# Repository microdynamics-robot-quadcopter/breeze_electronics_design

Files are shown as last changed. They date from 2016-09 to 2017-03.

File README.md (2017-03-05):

# breeze_electronics_design

## Description
This project is created and managed by EDA softwares, which contains the breeze quadcopter's component library, footprint library, schematic, printed circuit boards, etc.

## Note
Because of the changes in the project's requirements, we decided to use **Altium Designer** as the tool for developing the first edition of PCB rather than **KiCad**! So if you want to find the latest PCB design documents, please visit the **altium** directory.

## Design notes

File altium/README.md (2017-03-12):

# breeze_electronics_design





## Description
This project is created and managed by [Altium Designer](http://www.altium.com) softwares, which contains the breeze quadcopter's component library, footprint library, schematic, printed circuit boards, etc.

## Requirment
* Altium Designer 16.0.5(or higher version)

## Configuration
Open the Git Shell to download the **breeze_electronics_design** repository:
```bash
$> cd ~/Desktop
$> git clone https://github.com/microdynamics-quadcopter/breeze_electronics_design.git
```

Launch the **Altium Designer** software, and open **breeze_electronics_design.PrjPcb** file to view or develop PCB project.

## Schematic
* ### Motor
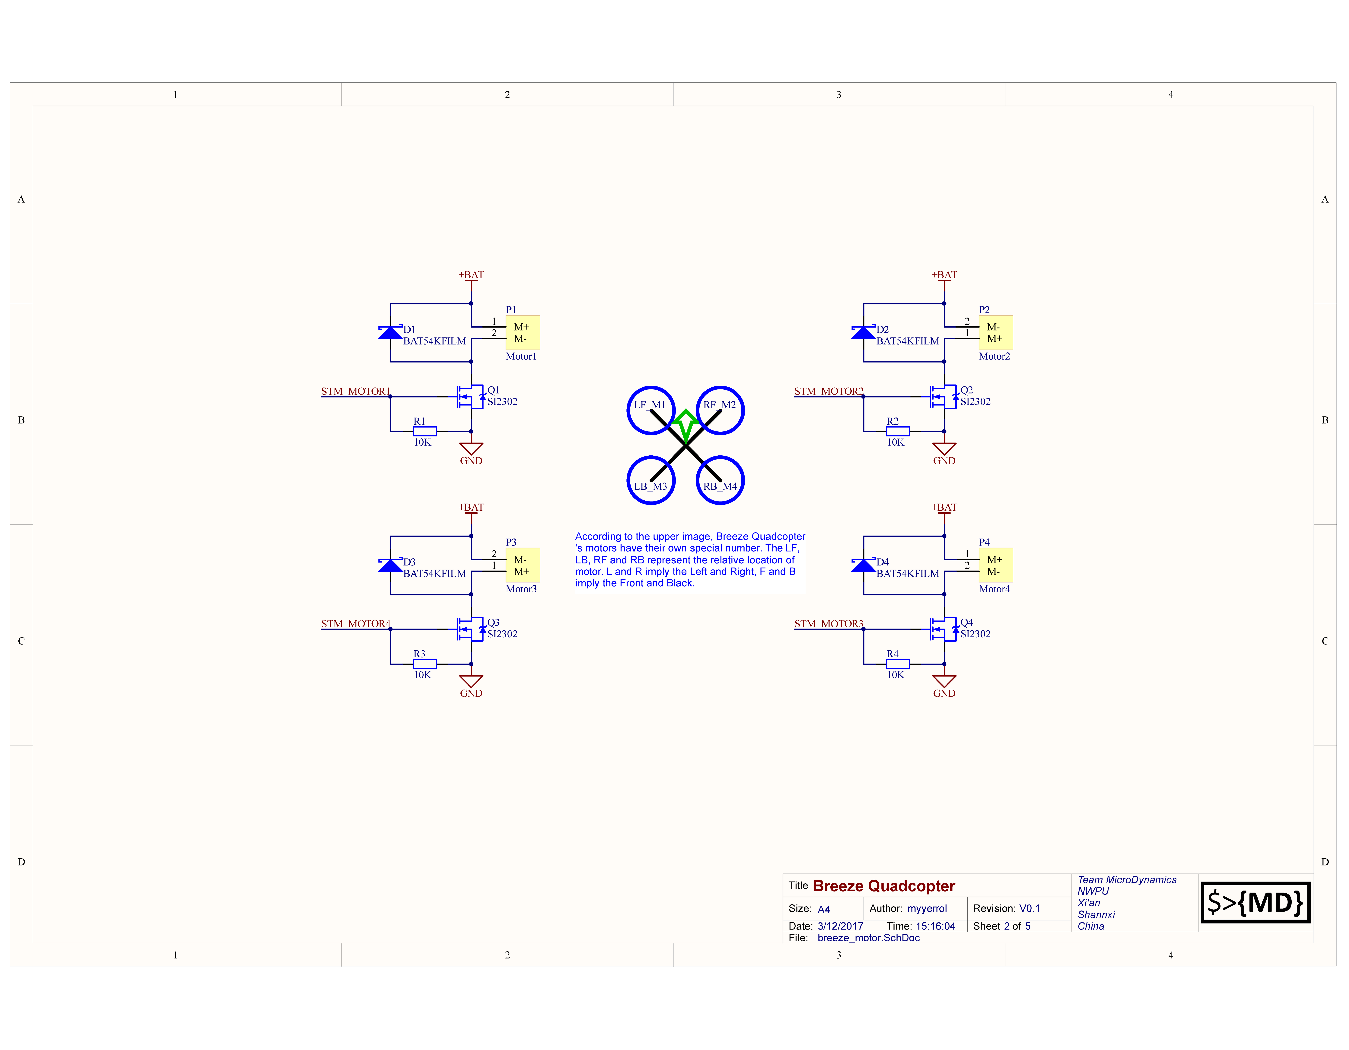
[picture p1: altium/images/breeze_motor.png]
breeze_motor


* ### Sensor
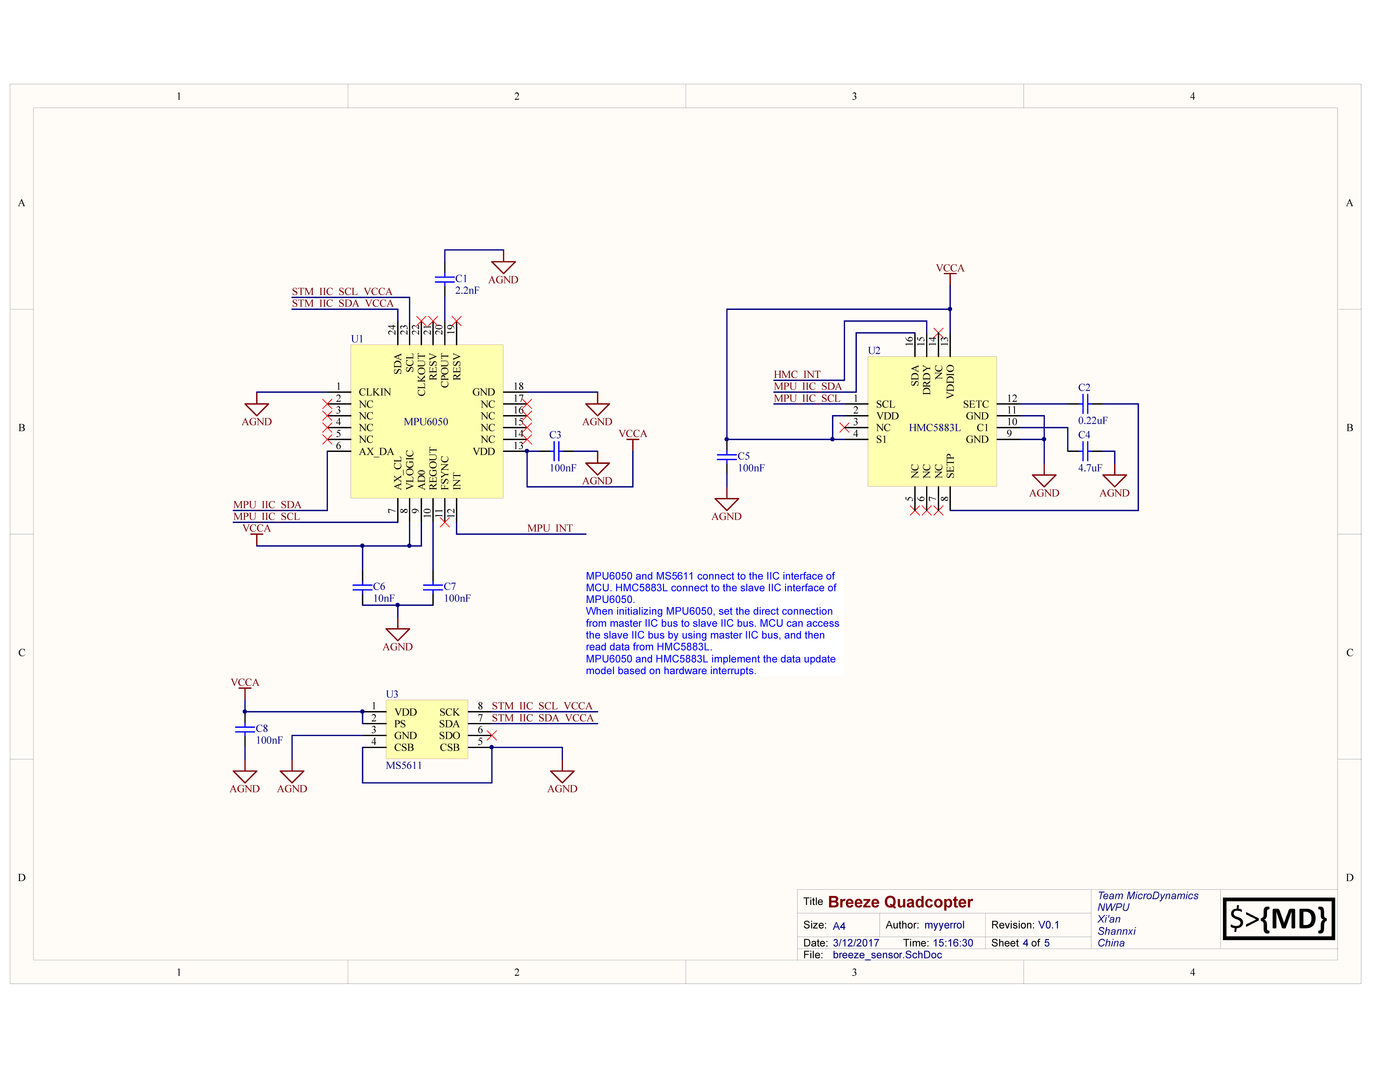
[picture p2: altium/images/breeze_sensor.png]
breeze_sensor


* ### Wireless
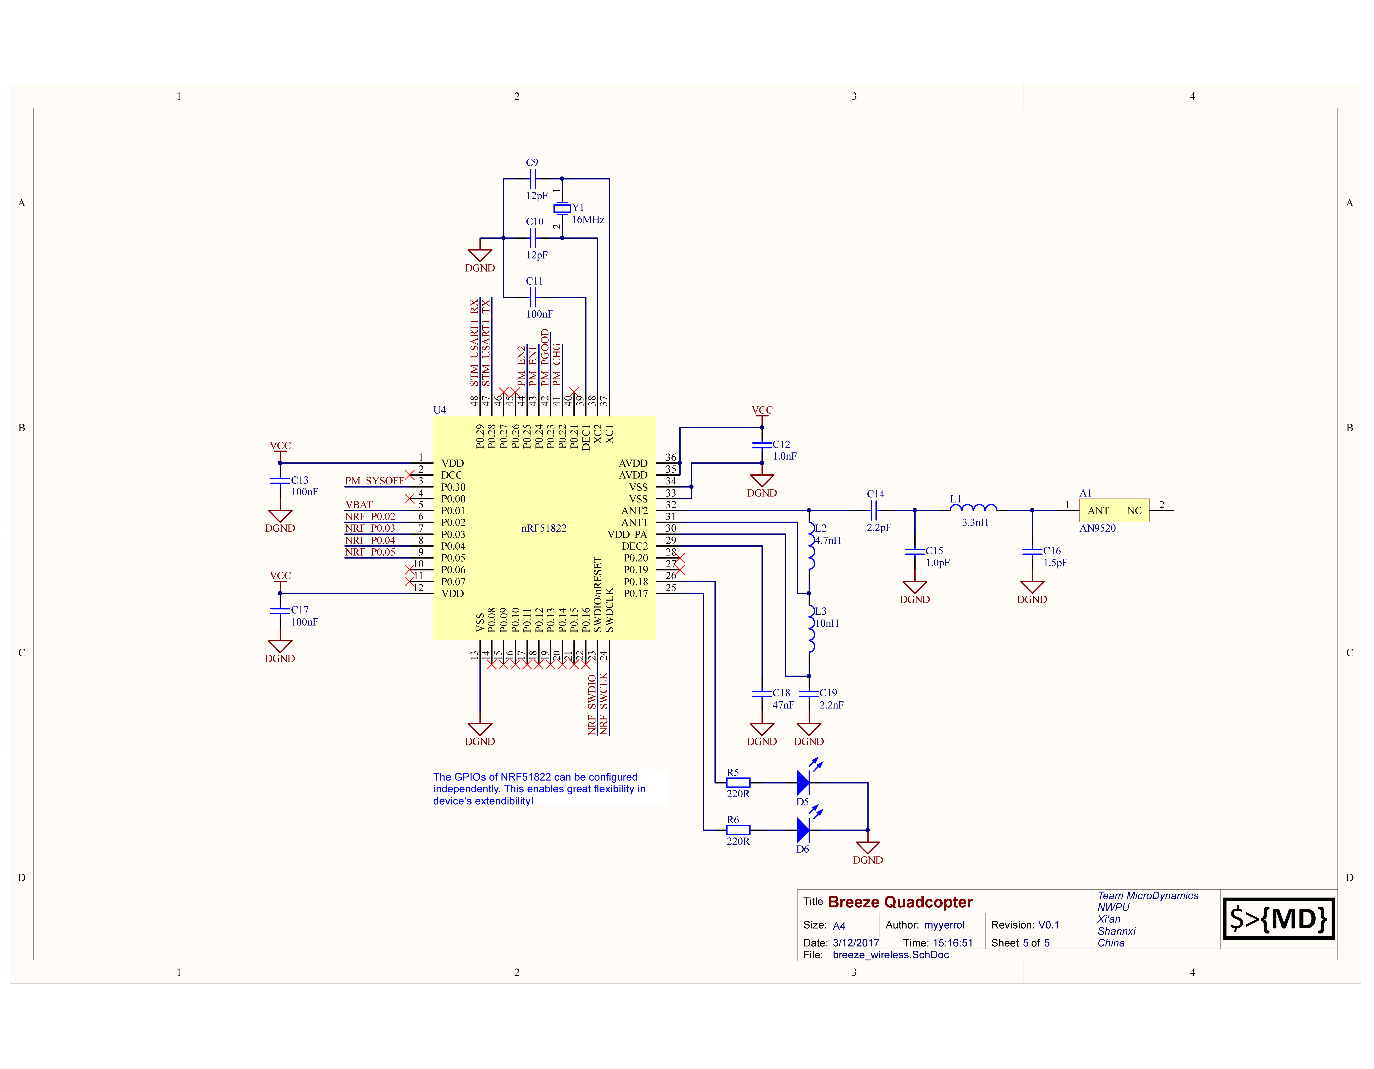
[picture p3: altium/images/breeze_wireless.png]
breeze_wireless


* ### Power
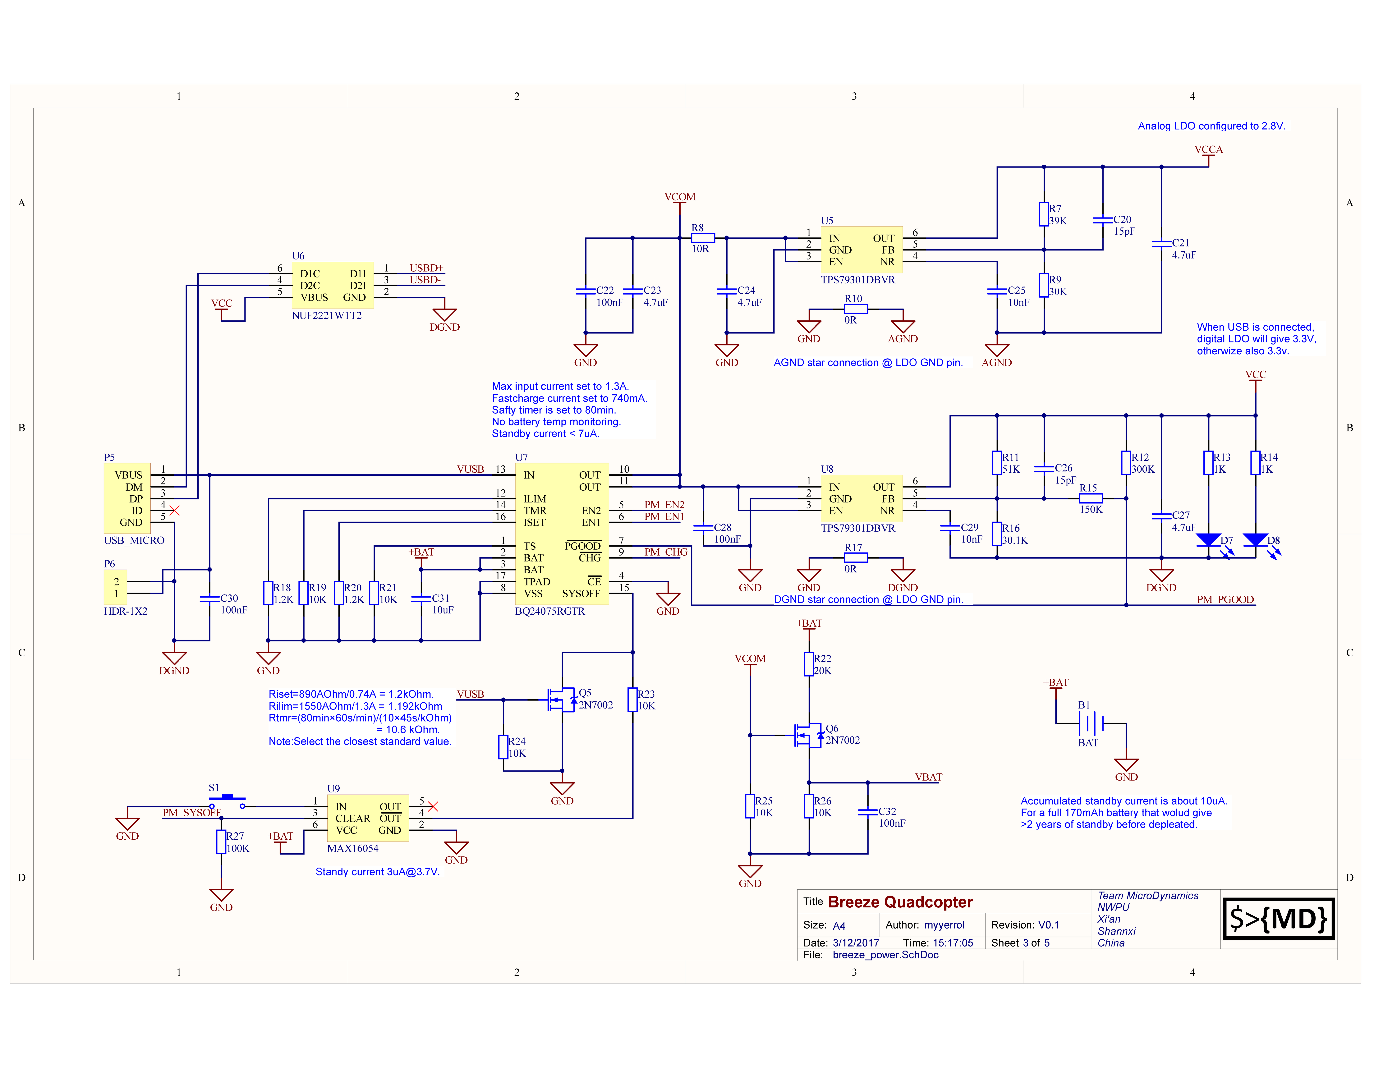
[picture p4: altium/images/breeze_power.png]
breeze_power


* ### Controller
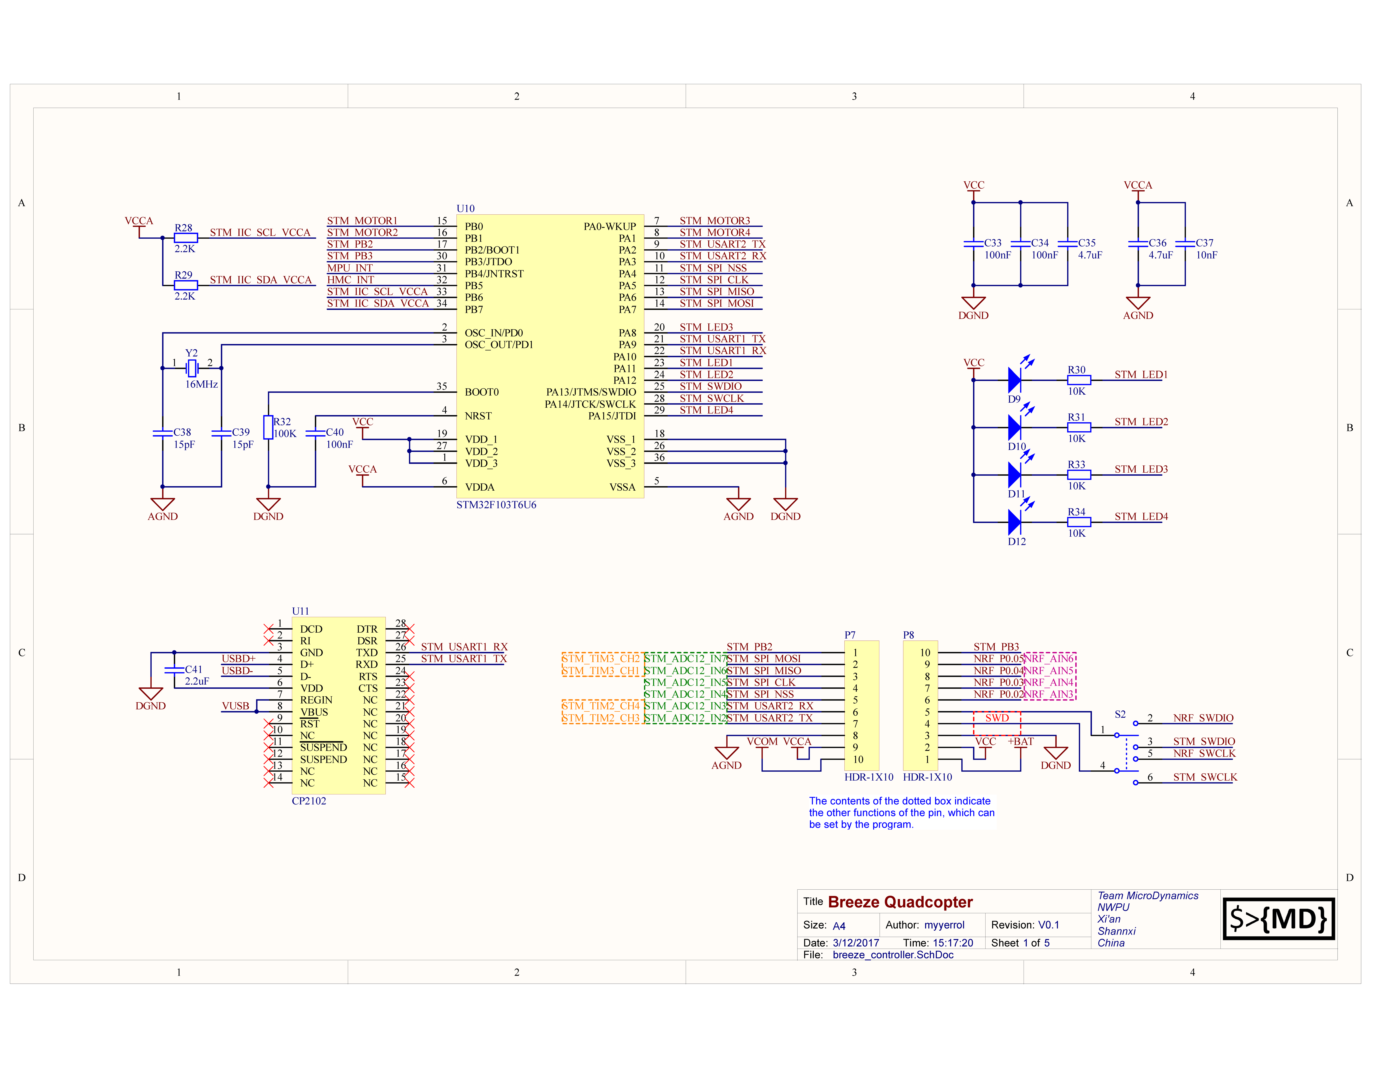
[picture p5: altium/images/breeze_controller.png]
breeze_controller


## PCB
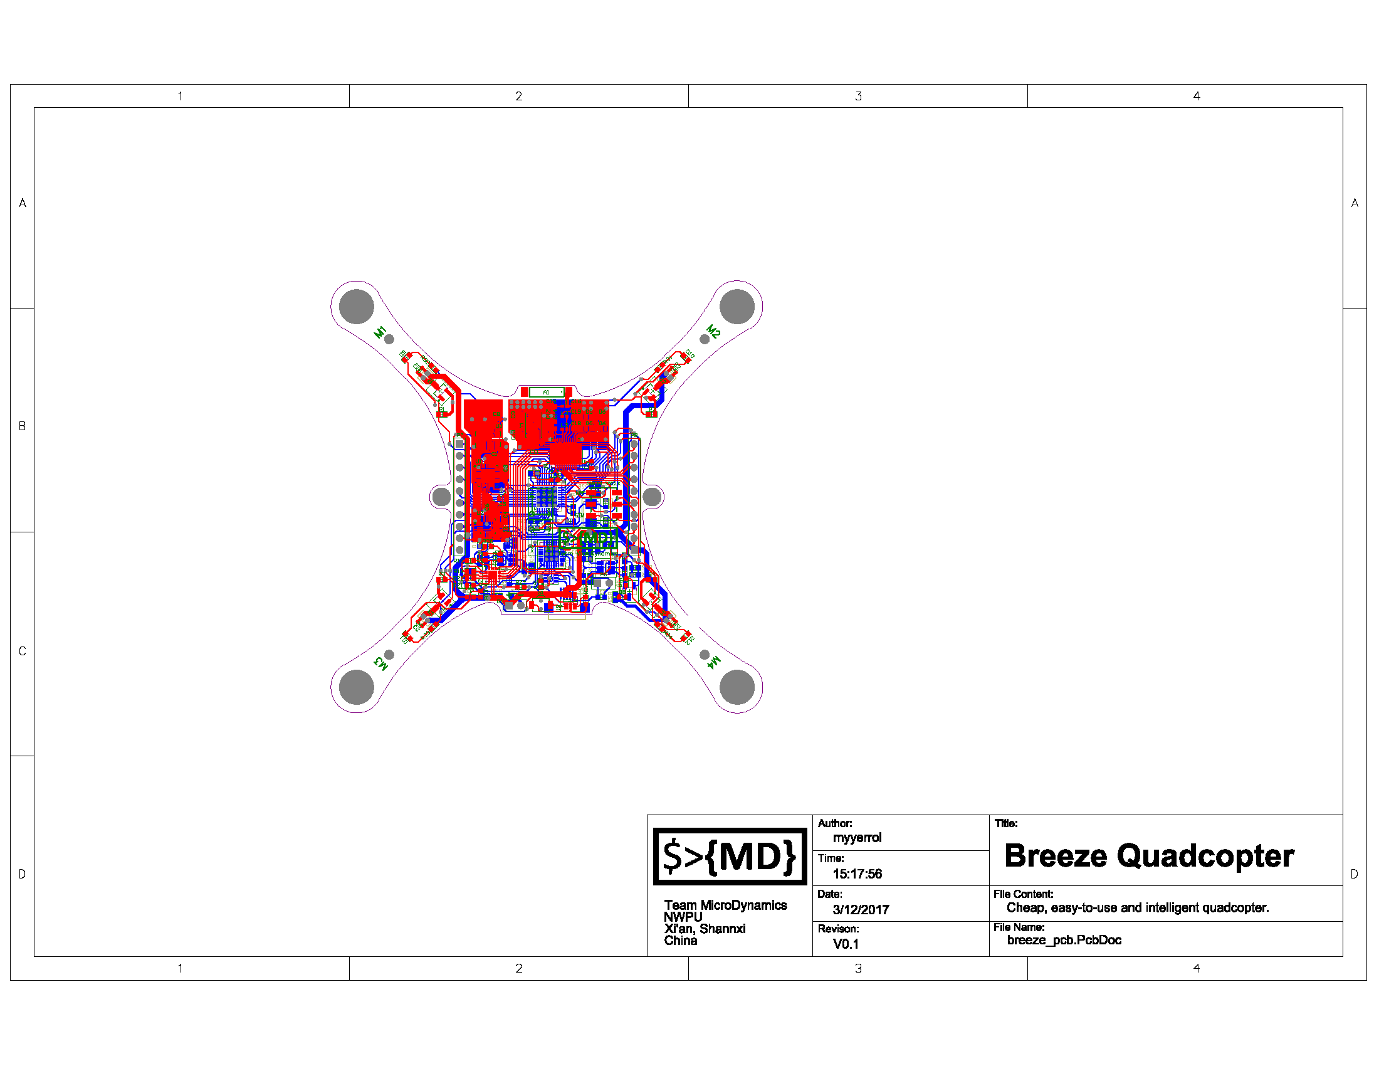
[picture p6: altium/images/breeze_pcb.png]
breeze_pcb


## Note
If you want to use our templates for schematic or pcb, please execute the **setup.bat** by double click.

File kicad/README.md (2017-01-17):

# breeze_electronics_design

## Description
This project is created and managed by [KiCad](http://kicad-pcb.org) software, which contains the breeze_std quadcopter's component library, footprint library, schematic, printed circuit boards, etc.

## PCB
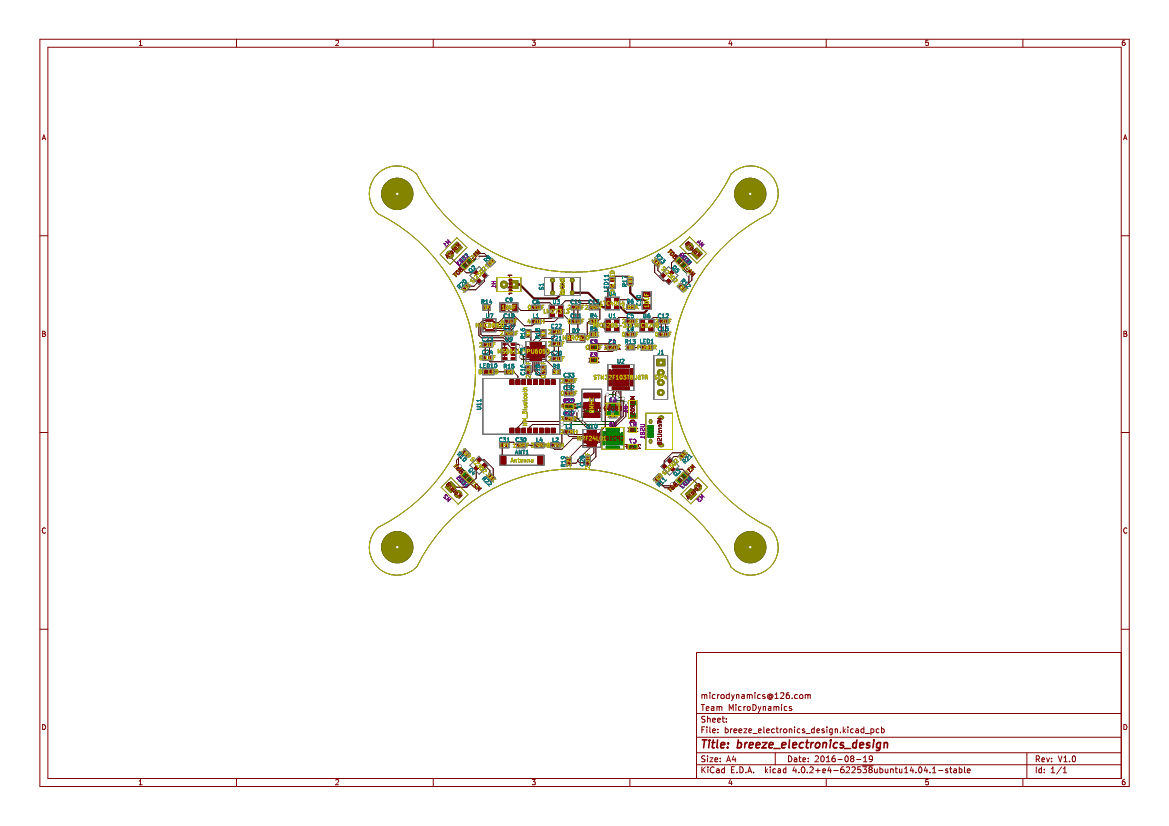
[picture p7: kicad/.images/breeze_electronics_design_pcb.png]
breeze_electronics_design_pcb


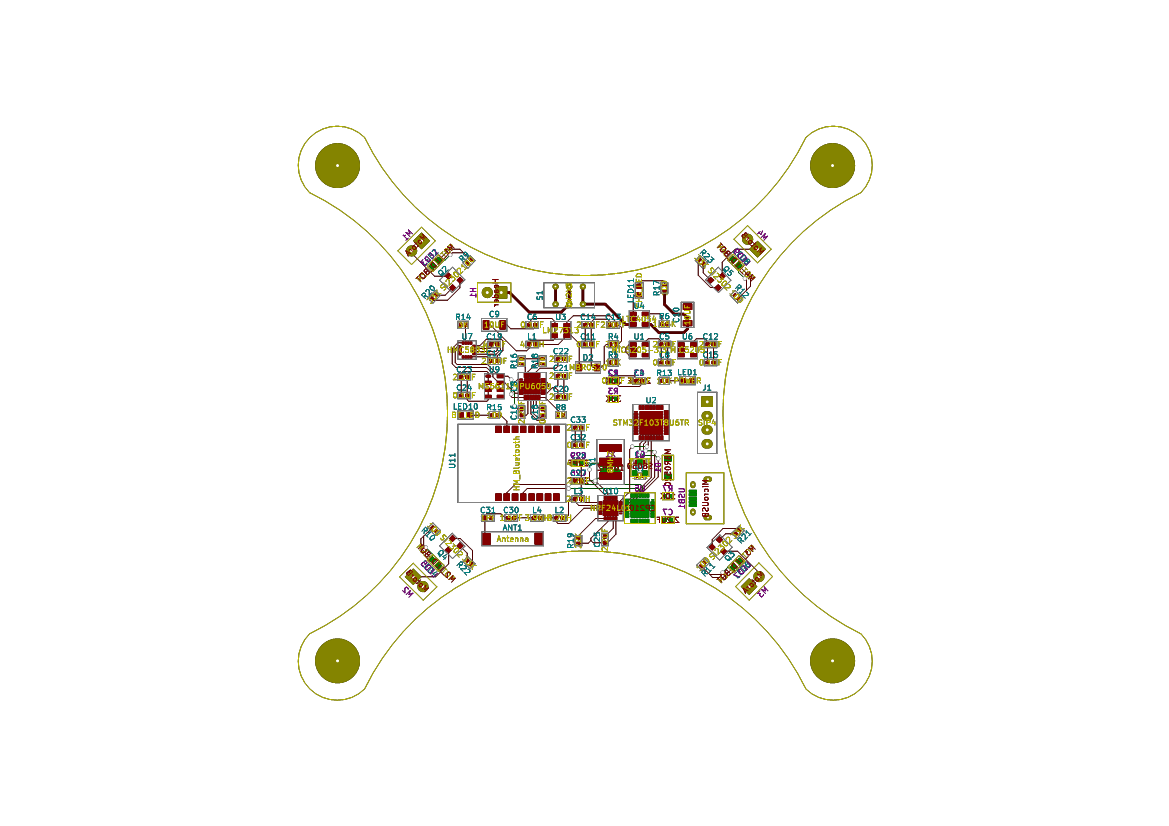
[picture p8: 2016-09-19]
kicad/.images/breeze_electronics_design_pcb_1.4.png

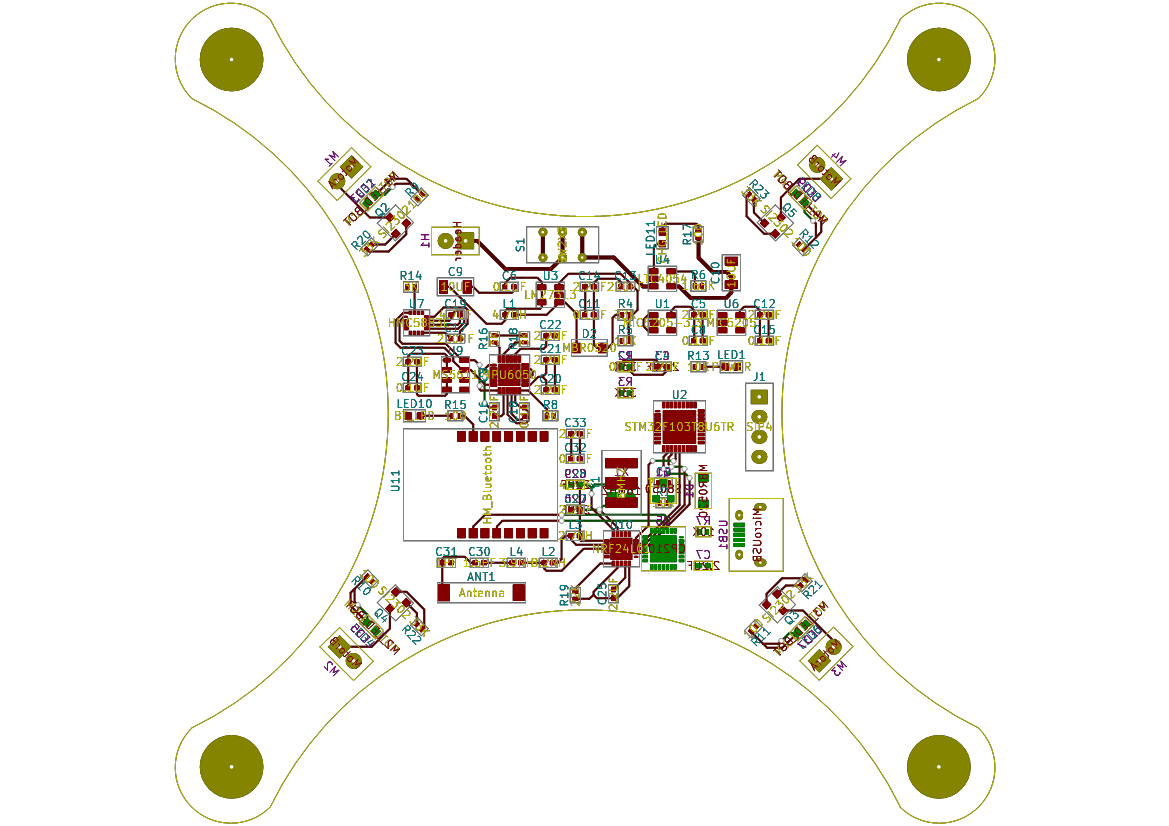
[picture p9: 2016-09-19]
kicad/.images/breeze_electronics_design_pcb_2.0.png

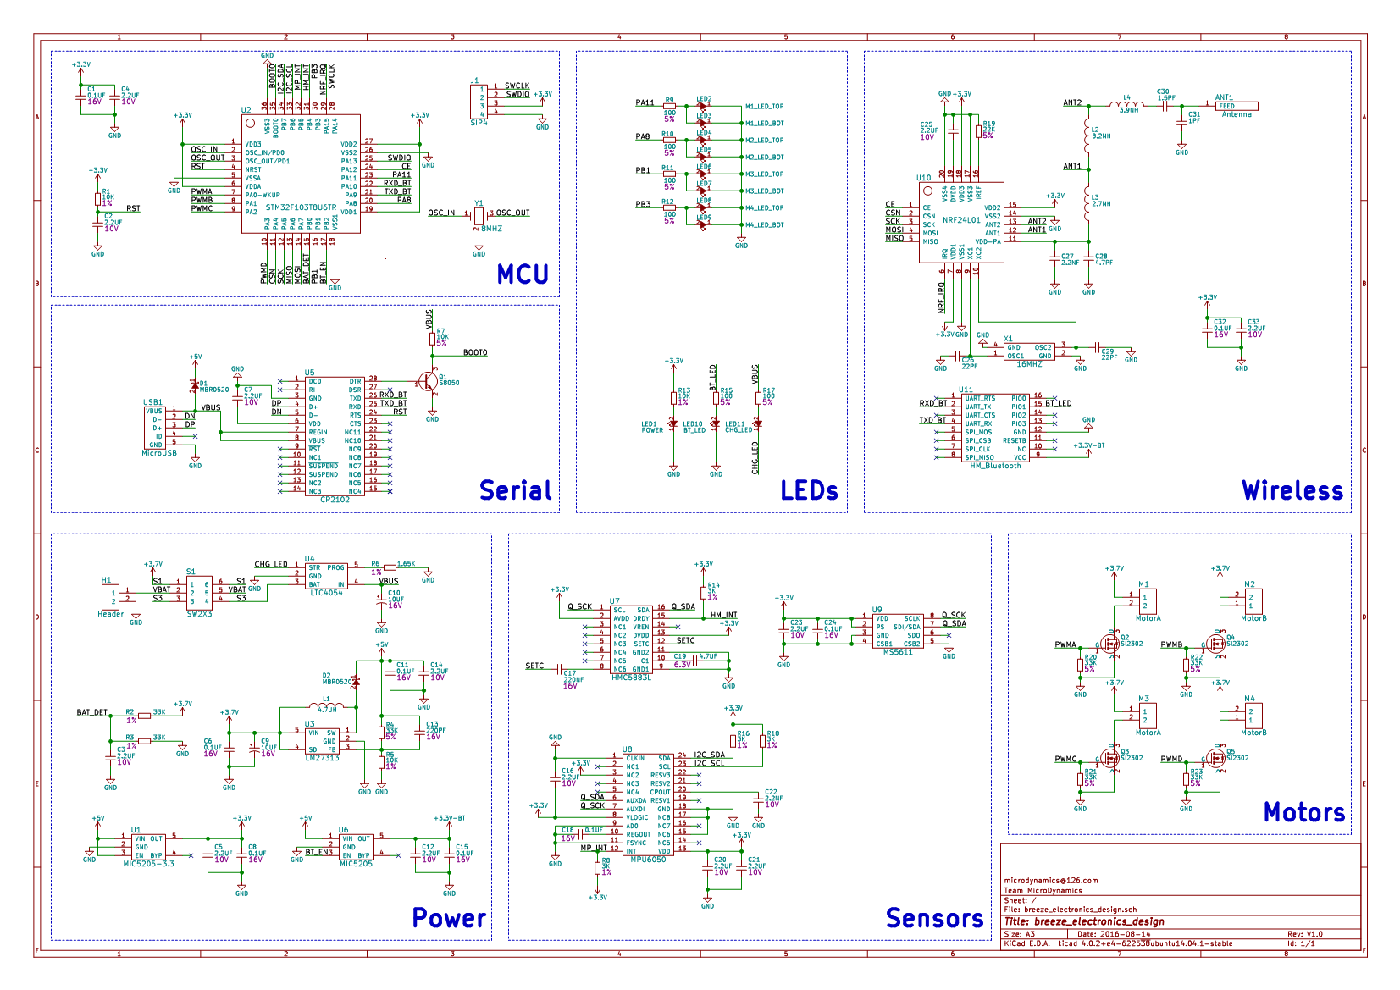
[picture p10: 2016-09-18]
kicad/.images/breeze_electronics_design_sch.png

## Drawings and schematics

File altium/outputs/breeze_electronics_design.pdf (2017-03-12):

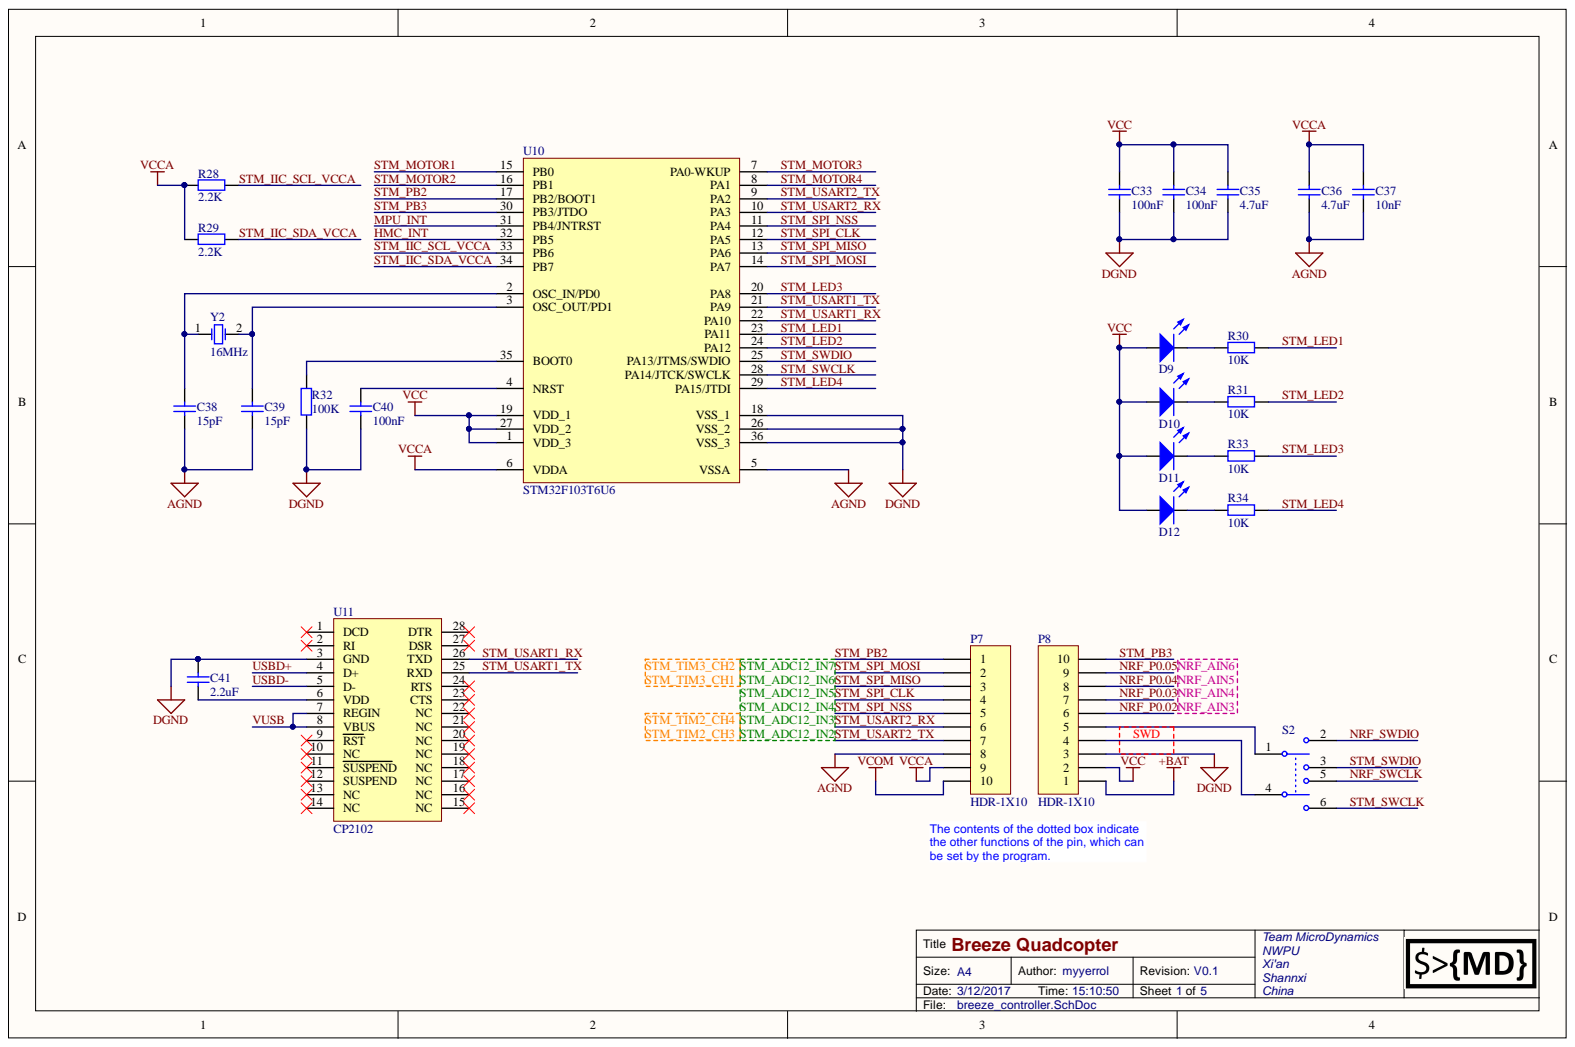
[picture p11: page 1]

The contents of the dotted box indicate
the other functions of the pin, which can
be set by the program.

Title Breeze Quadcopter | Team MicroDynamics NWPU Xi'an Shannxi China

Size: A4 | Author: myyerrol | Revision: V0.1
Date: 3/12/2017 Time: 15:10:50 | | Sheet 1 of 5
File: breeze_controller.SchDoc

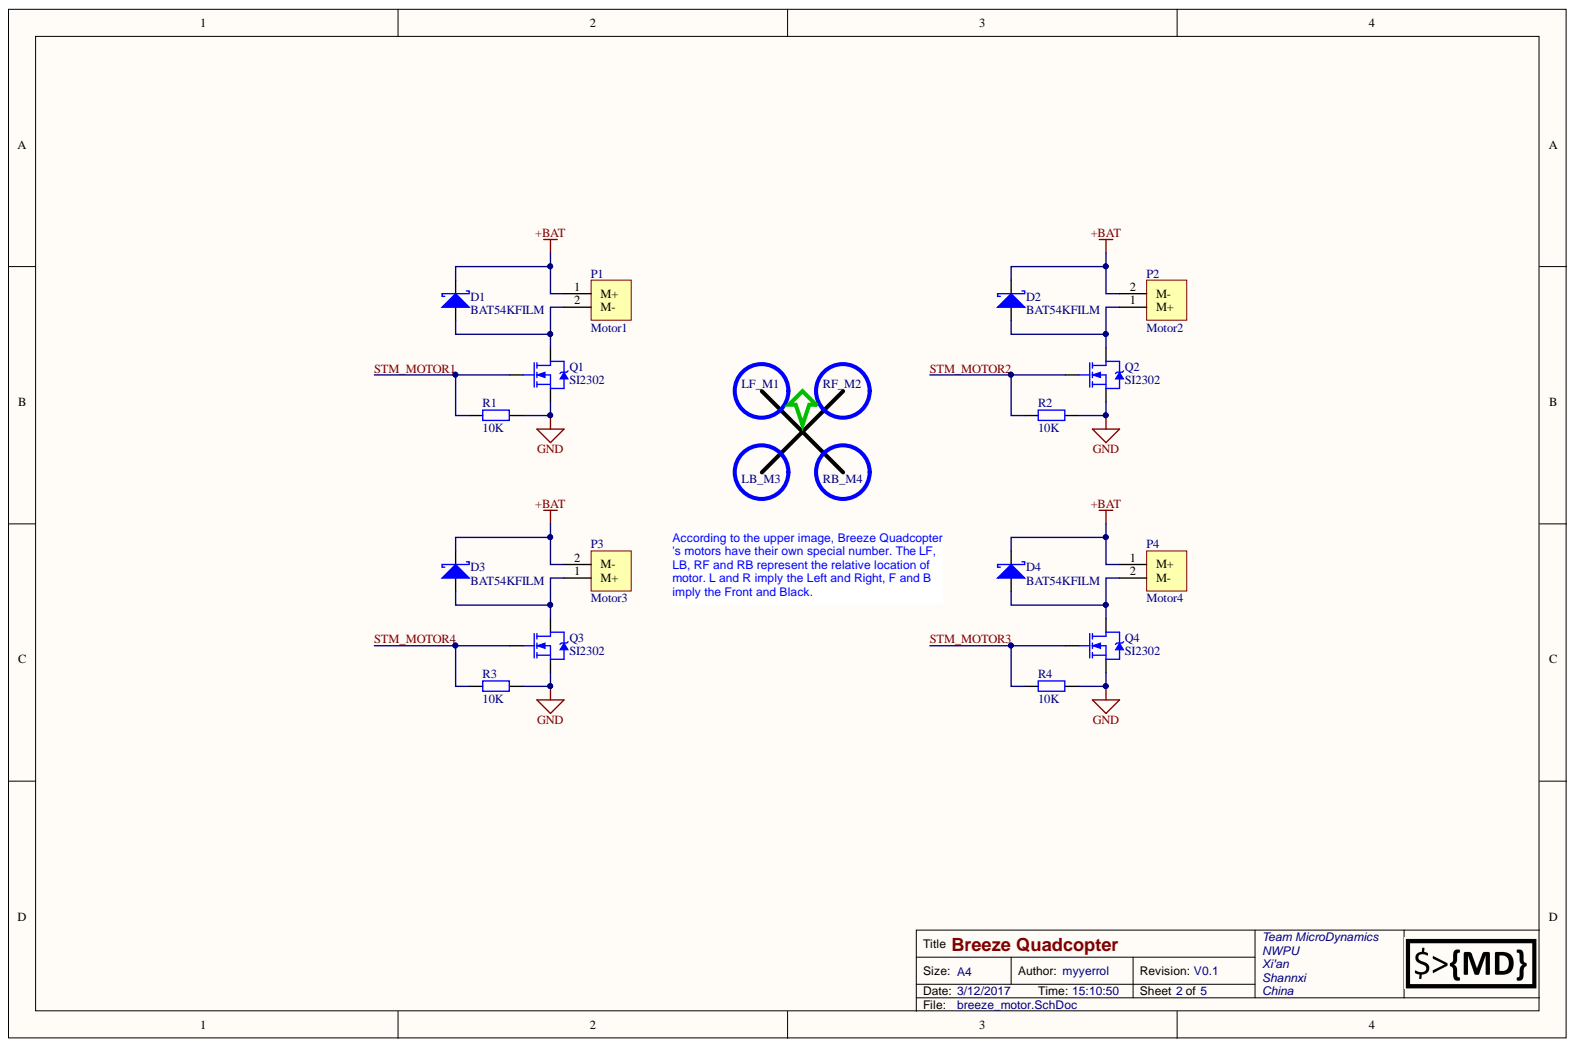
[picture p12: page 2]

According to the upper image, Breeze Quadcopter
's motors have their own special number. The LF,
LB, RF and RB represent the relative location of
motor. L and R imply the Left and Right, F and B
imply the Front and Black.

Title Breeze Quadcopter | Team MicroDynamics NWPU Xi'an Shannxi China

Size: A4 | Author: myyerrol | Revision: V0.1
Date: 3/12/2017 Time: 15:10:50 | | Sheet 2 of 5
File: breeze_motor.SchDoc

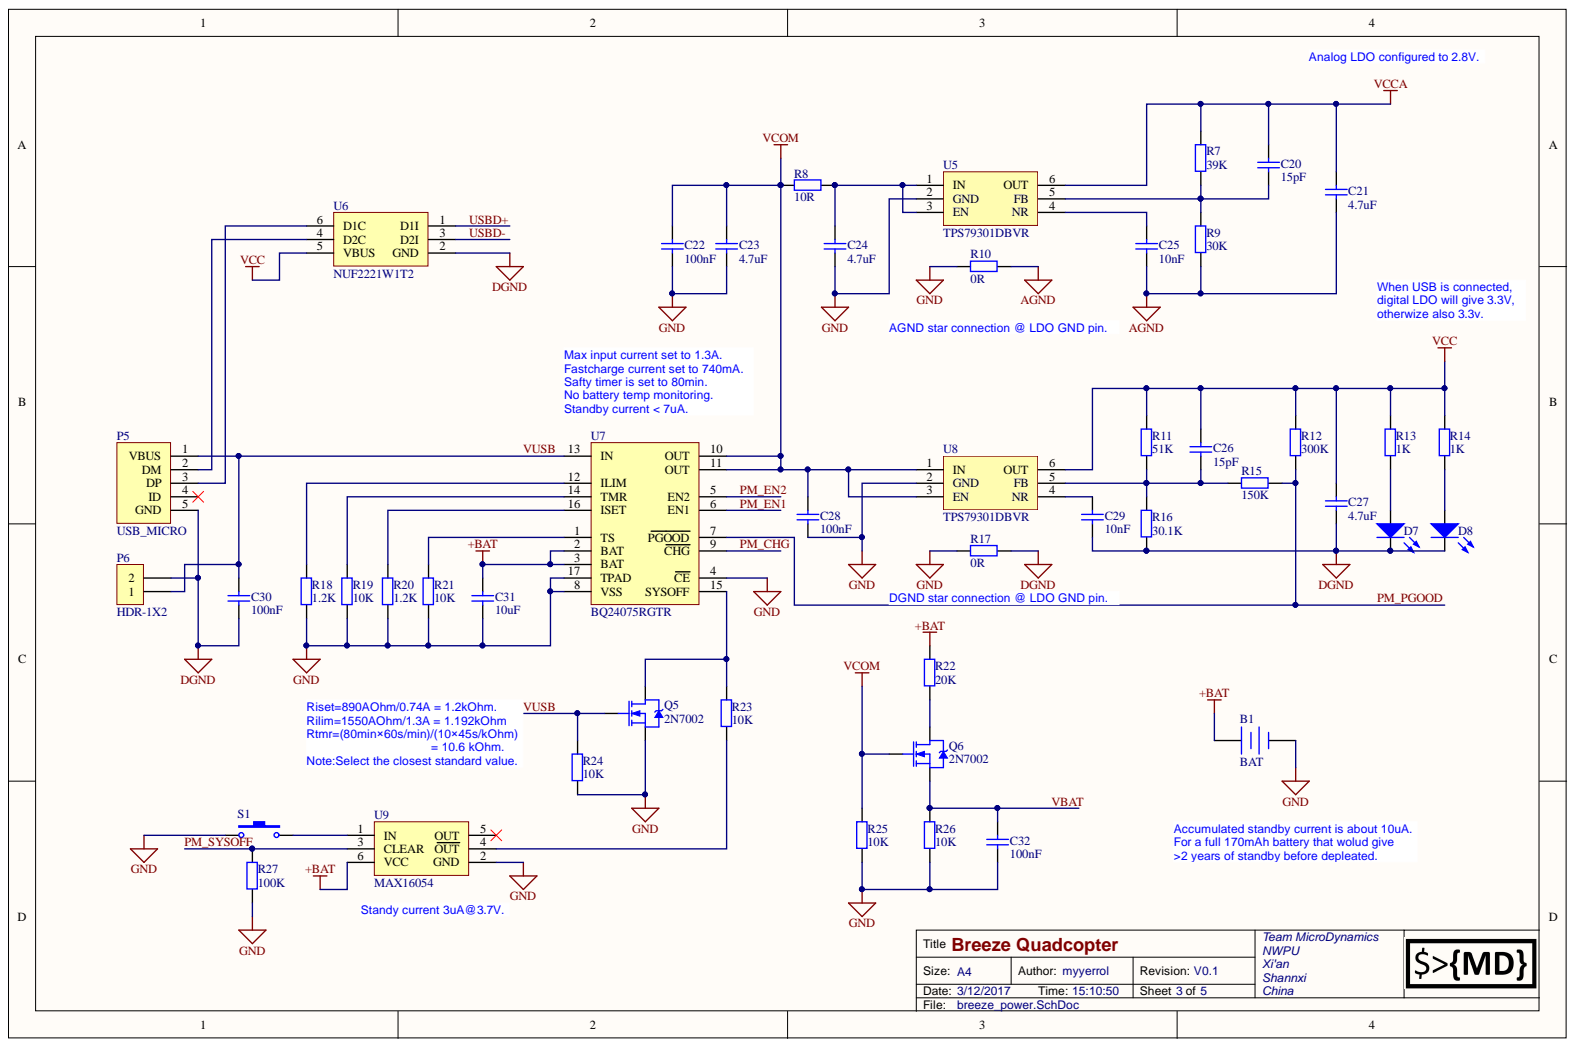
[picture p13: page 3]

Analog LDO configured to 2.8V.

When USB is connected,
digital LDO will give 3.3V,
otherwize also 3.3v.

AGND star connection @ LDO GND pin.

Max input current set to 1.3A.
Fastcharge current set to 740mA.
Safty timer is set to 80min.
No battery temp monitoring.
Standby current < 7uA.

DGND star connection @ LDO GND pin.

Note:Select the closest standard value.

Accumulated standby current is about 10uA.
For a full 170mAh battery that wolud give
>2 years of standby before depleated.

Title Breeze Quadcopter | Team MicroDynamics NWPU Xi'an Shannxi China

Size: A4 | Author: myyerrol | Revision: V0.1
Date: 3/12/2017 Time: 15:10:50 | | Sheet 3 of 5
File: breeze_power.SchDoc

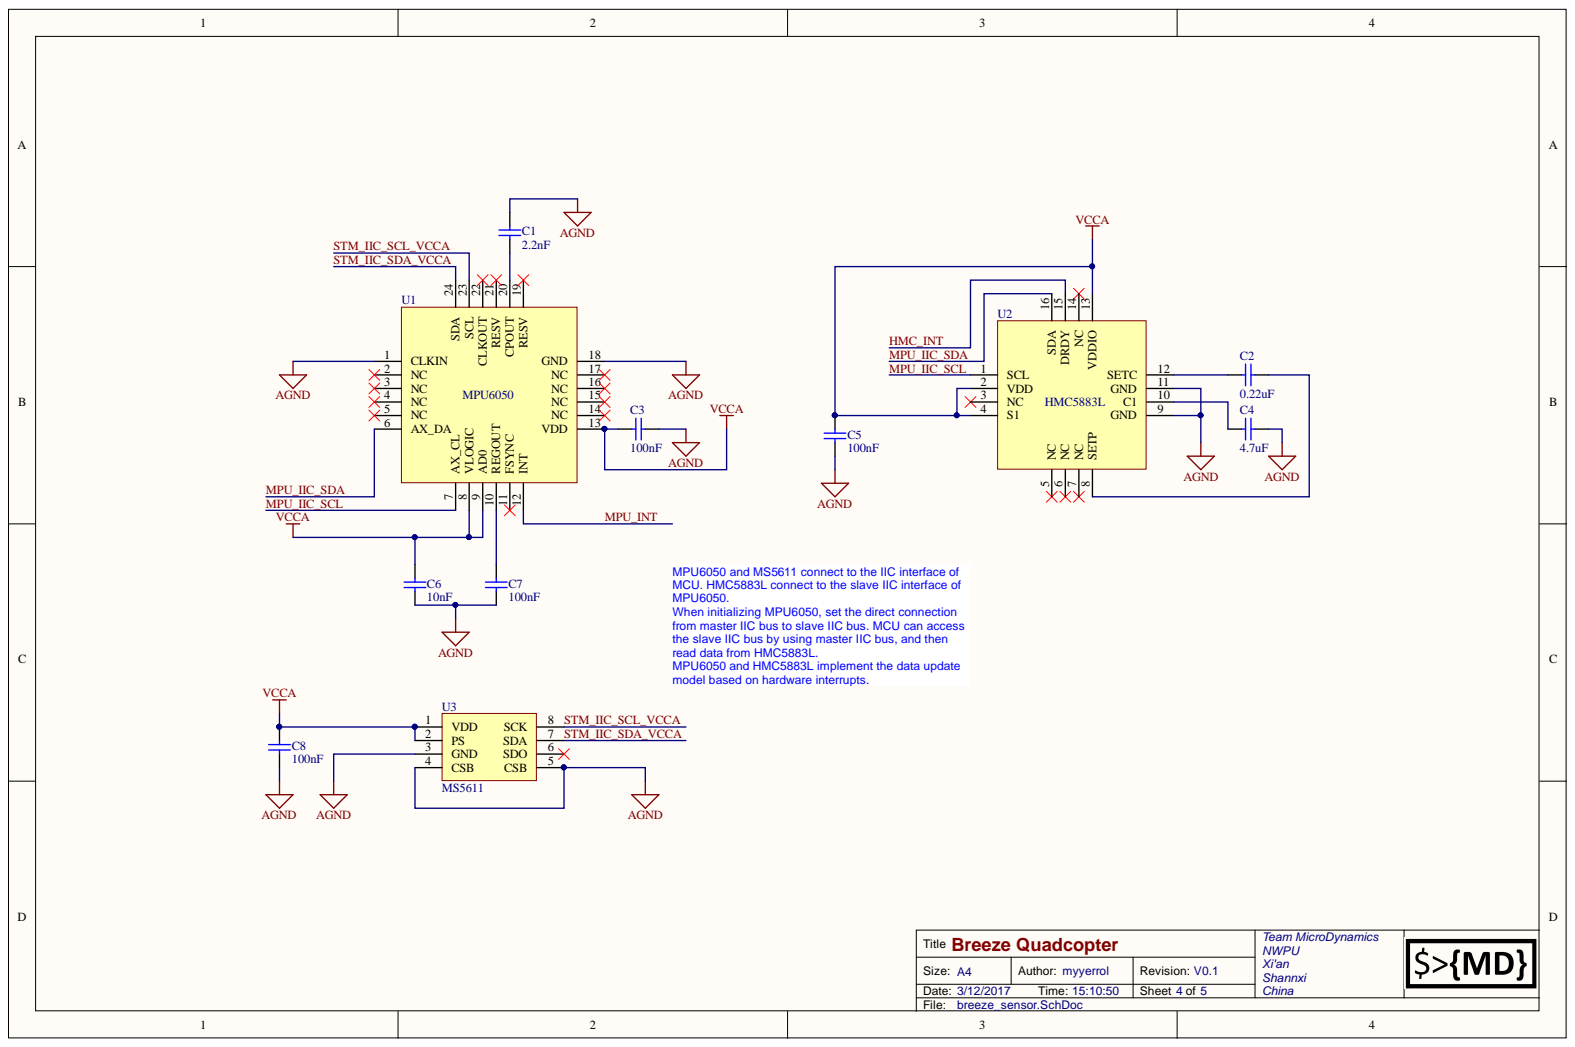
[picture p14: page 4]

12 DDIO 13 NC 14 DRDY 15 SDA 16

MPU6050 and MS5611 connect to the IIC interface of
MCU. HMC5883L connect to the slave IIC interface of
MPU6050.
When initializing MPU6050, set the direct connection
from master IIC bus to slave IIC bus. MCU can access
the slave IIC bus by using master IIC bus, and then
read data from HMC5883L.
MPU6050 and HMC5883L implement the data update
model based on hardware interrupts.

Title Breeze Quadcopter | Team MicroDynamics NWPU Xi'an Shannxi China

Size: A4 | Author: myyerrol | Revision: V0.1
Date: 3/12/2017 Time: 15:10:50 | | Sheet 4 of 5
File: breeze_sensor.SchDoc

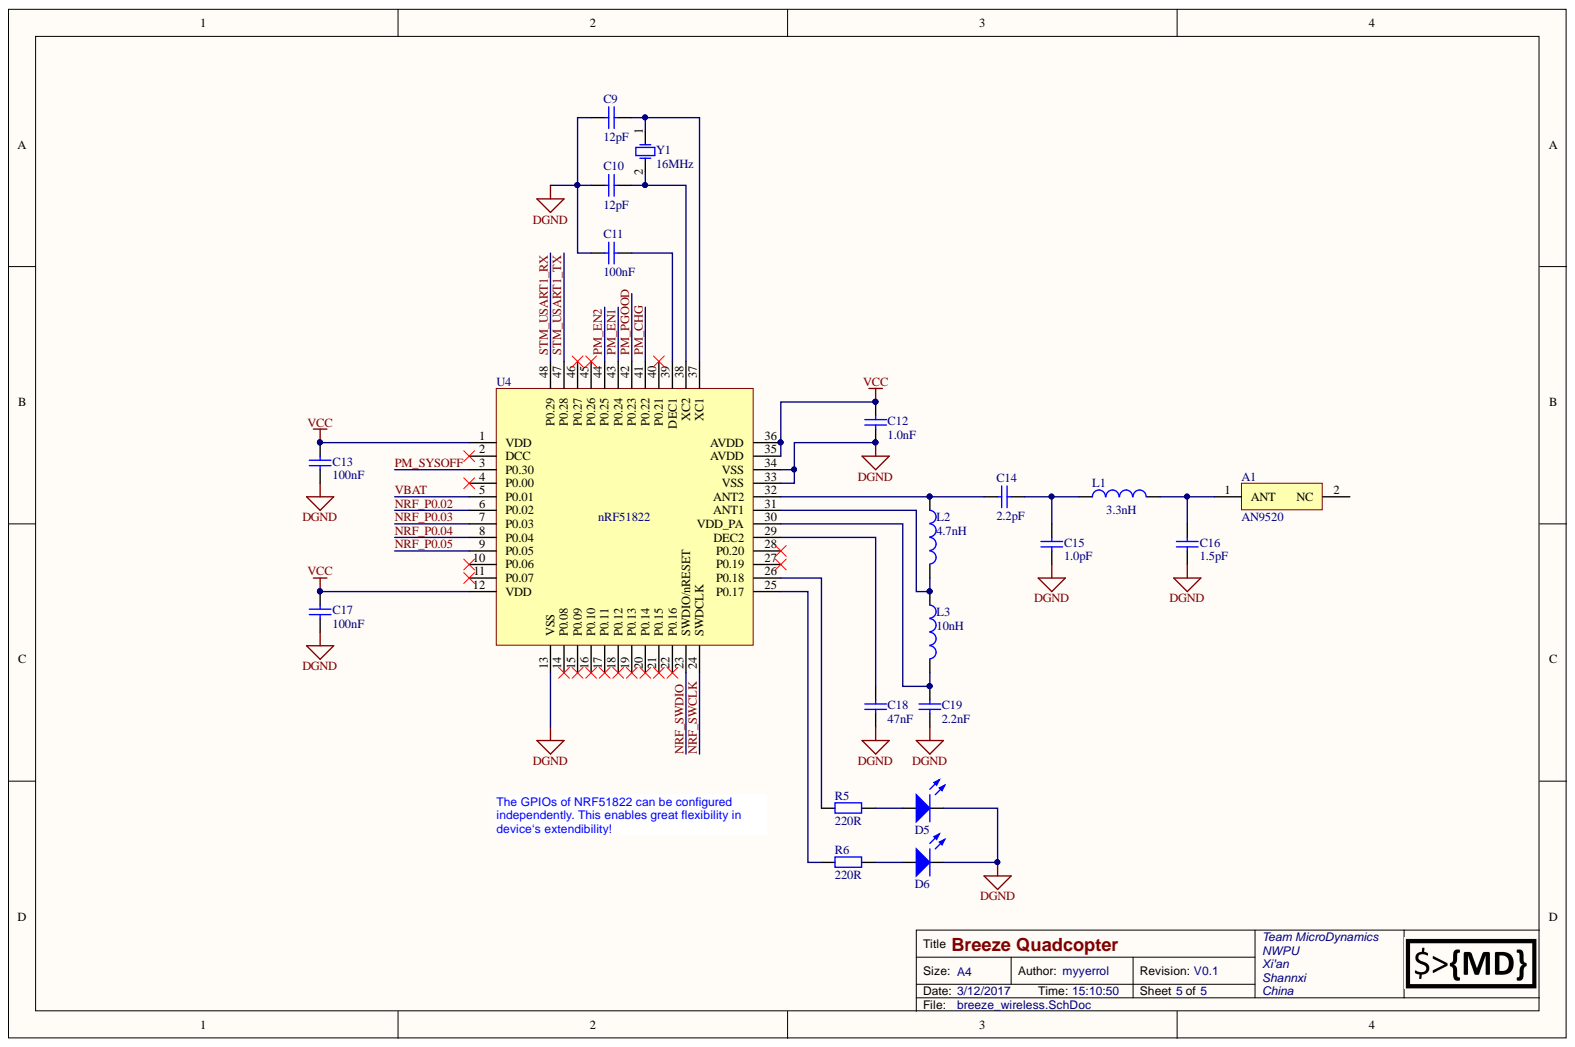
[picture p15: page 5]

The GPIOs of NRF51822 can be configured
independently. This enables great flexibility in
device‘s extendibility!

Title Breeze Quadcopter | Team MicroDynamics NWPU Xi'an Shannxi China

Size: A4 | Author: myyerrol | Revision: V0.1
Date: 3/12/2017 Time: 15:10:50 | | Sheet 5 of 5
File: breeze_wireless.SchDoc

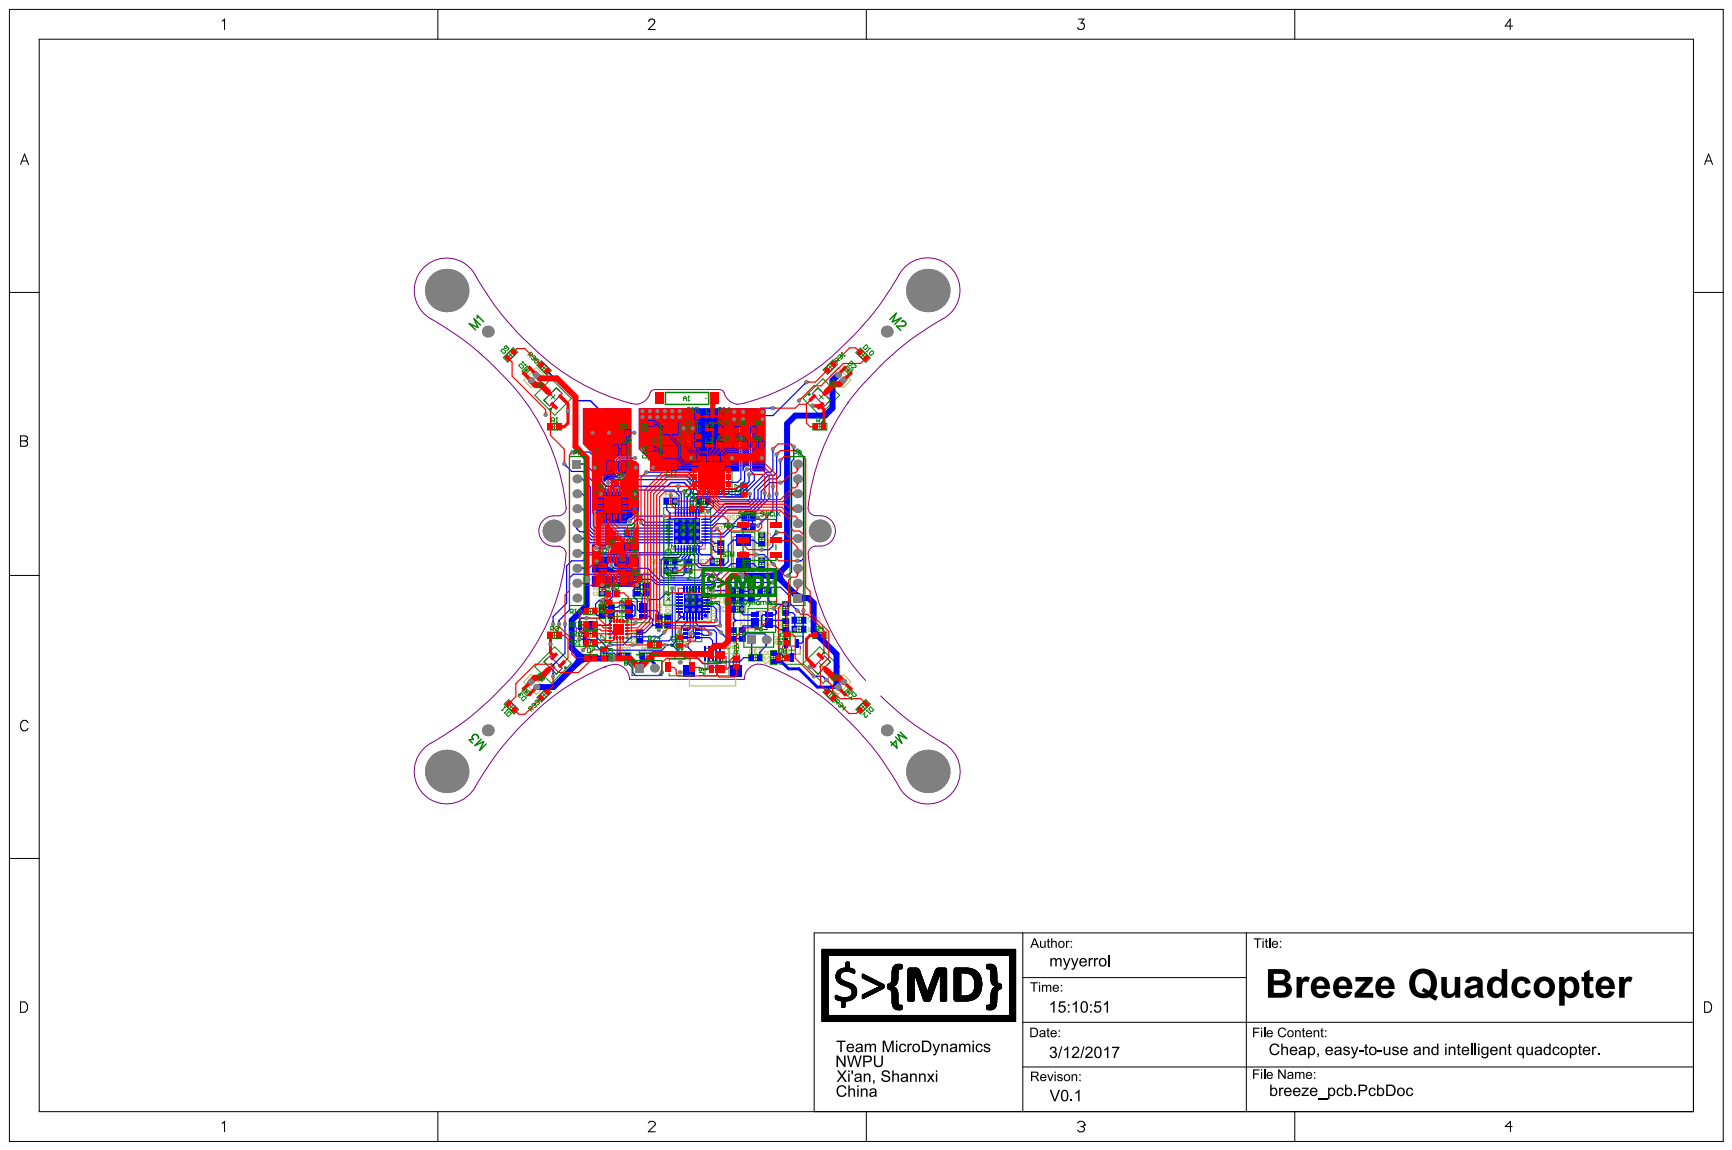
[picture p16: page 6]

| 3/12/2017 | 15:10:53
Print Date: | 12-Mar-17 | 3:10:58 PM
AN9520 | AN9520 | AN9520 | A1 | 2.4GHz Wireless Communication Antenna | 1
HDR-1X2 | BAT | BAT | B1 | Battery | 1
SMD-0603 | CAP-0603 | CAP-0603 | C1, C2, C3, C4, C5, C6, C7, C8, C9, C10,
| | | C11, C12, C13, C14, C15, C16, C17, C18,
| | | C19, C20, C21, C22, C23, C24, C25, C26,
| | | C27, C28, C29, C30, C31, C32, C33, C34,
| | | C35, C36, C37, C38, C39, C40, C41 | Capacitor | 41
SOD-523 | BAT54KFILM | BAT54KFILM | D1, D2, D3, D4 | Schottky Diode | 4
SMD-0603 | LED-0603 | LED-0603 | D5, D6, D7, D8, D9, D10, D11, D12 | LED | 8
SMD-0402 | IND-0402 | IND-0402 | L1, L2, L3 | Inductor | 3
HDRM-1X2 | Motor1 | Motor_A | P1 | Motor Header | 1
HDRM-1X2 | Motor2 | Motor_B | P2 | Motor Header | 1
HDRM-1X2 | Motor3 | Motor_B | P3 | Motor Header | 1
HDRM-1X2 | Motor4 | Motor_A | P4 | Motor Header | 1
USB_MICRO | USB_MICRO | USB_MICRO | P5 | Micro USB | 1
HDR-1X2 | HDR-1X2 | HDR-1X2 | P6 | Header 1X2 | 1
HDR-1X10 | HDR-1X10 | HDR-1X10 | P7, P8 | Header 1X10 | 2
SOT-23 | SI2302 | SI2302 | Q1, Q2, Q3, Q4 | N-Channel Enhancement Mode Field Effect
| | | | Transistor | 4
SOT-23 | 2N7002 | 2N7002 | Q5, Q6 | N-Channel Enhancement Mode Field Effect
| | | | Transistor | 2
SMD-0603 | RES-0603 | RES-0603 | R1, R2, R3, R4, R5, R6, R7, R8, R9, R10,
| | | R11, R12, R13, R14, R15, R16, R17, R18,
| | | R19, R20, R21, R22, R23, R24, R25, R26,
| | | R27, R28, R29, R30, R31, R32, R33, R34 | Resistor | 34
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

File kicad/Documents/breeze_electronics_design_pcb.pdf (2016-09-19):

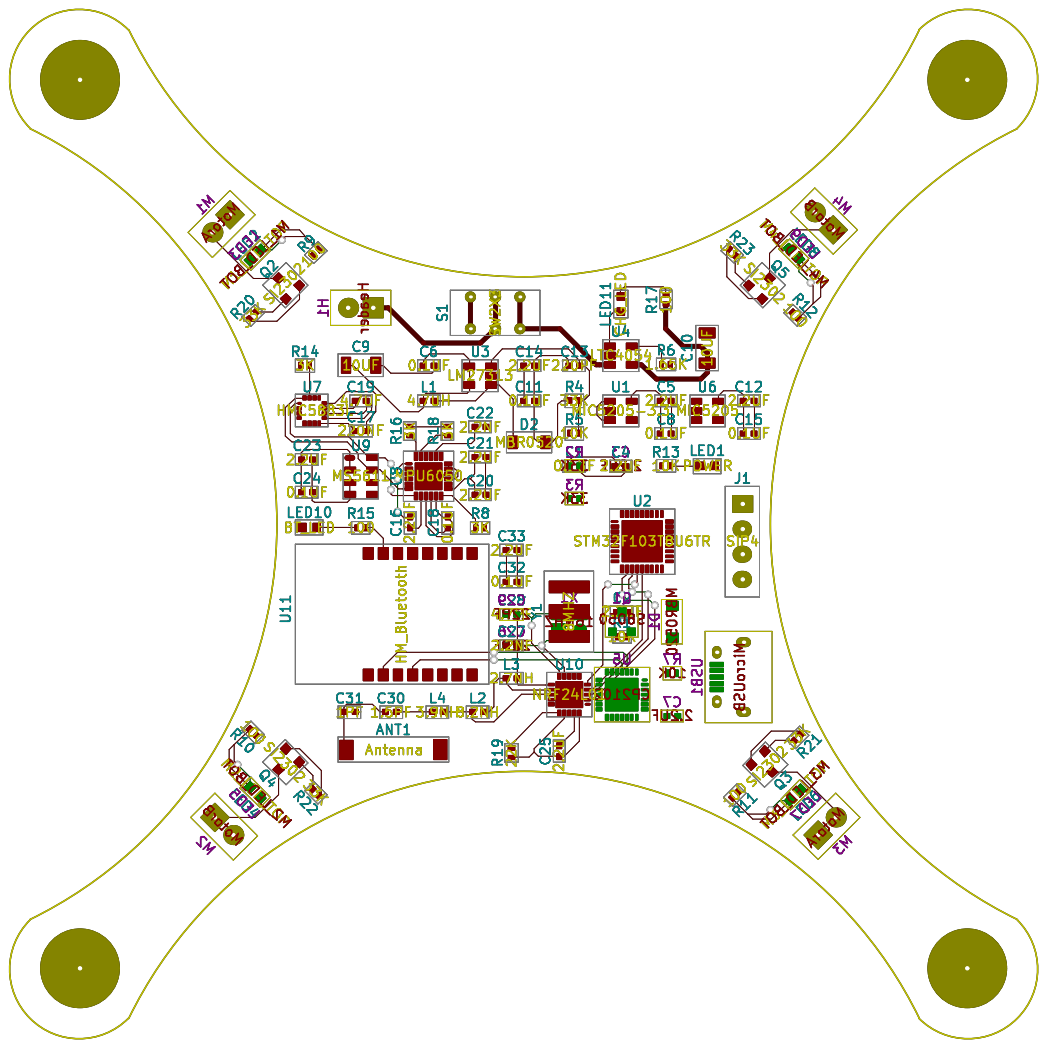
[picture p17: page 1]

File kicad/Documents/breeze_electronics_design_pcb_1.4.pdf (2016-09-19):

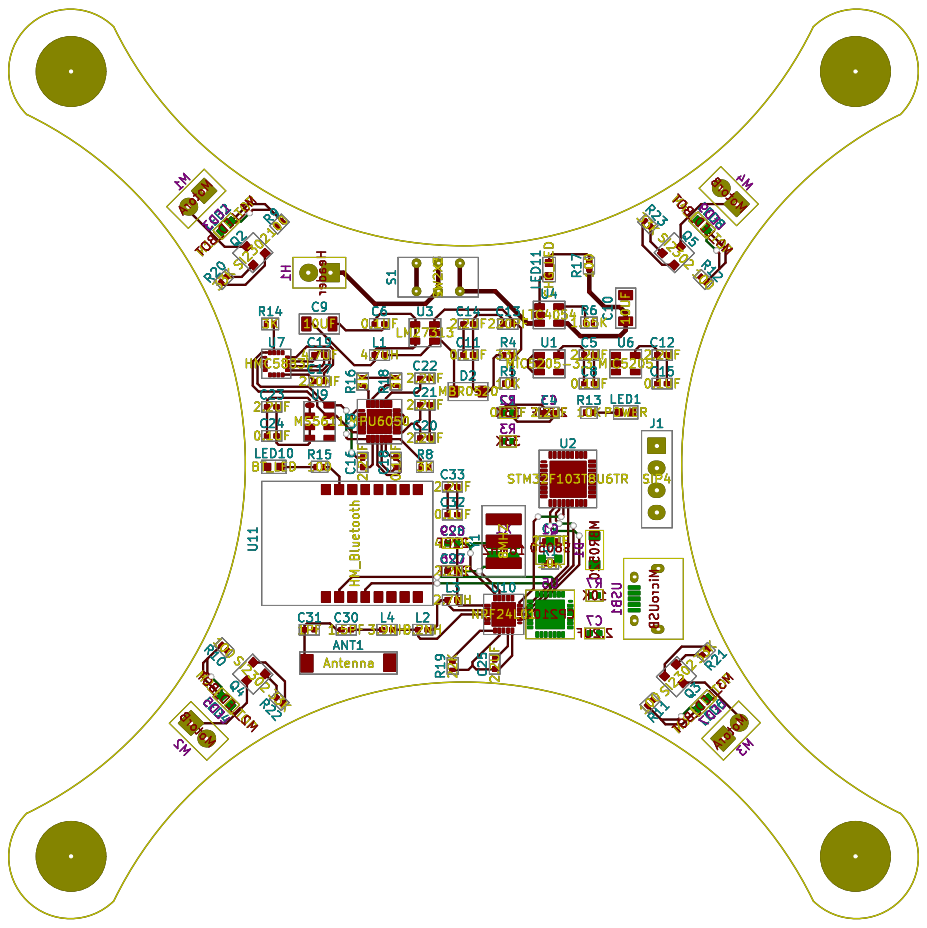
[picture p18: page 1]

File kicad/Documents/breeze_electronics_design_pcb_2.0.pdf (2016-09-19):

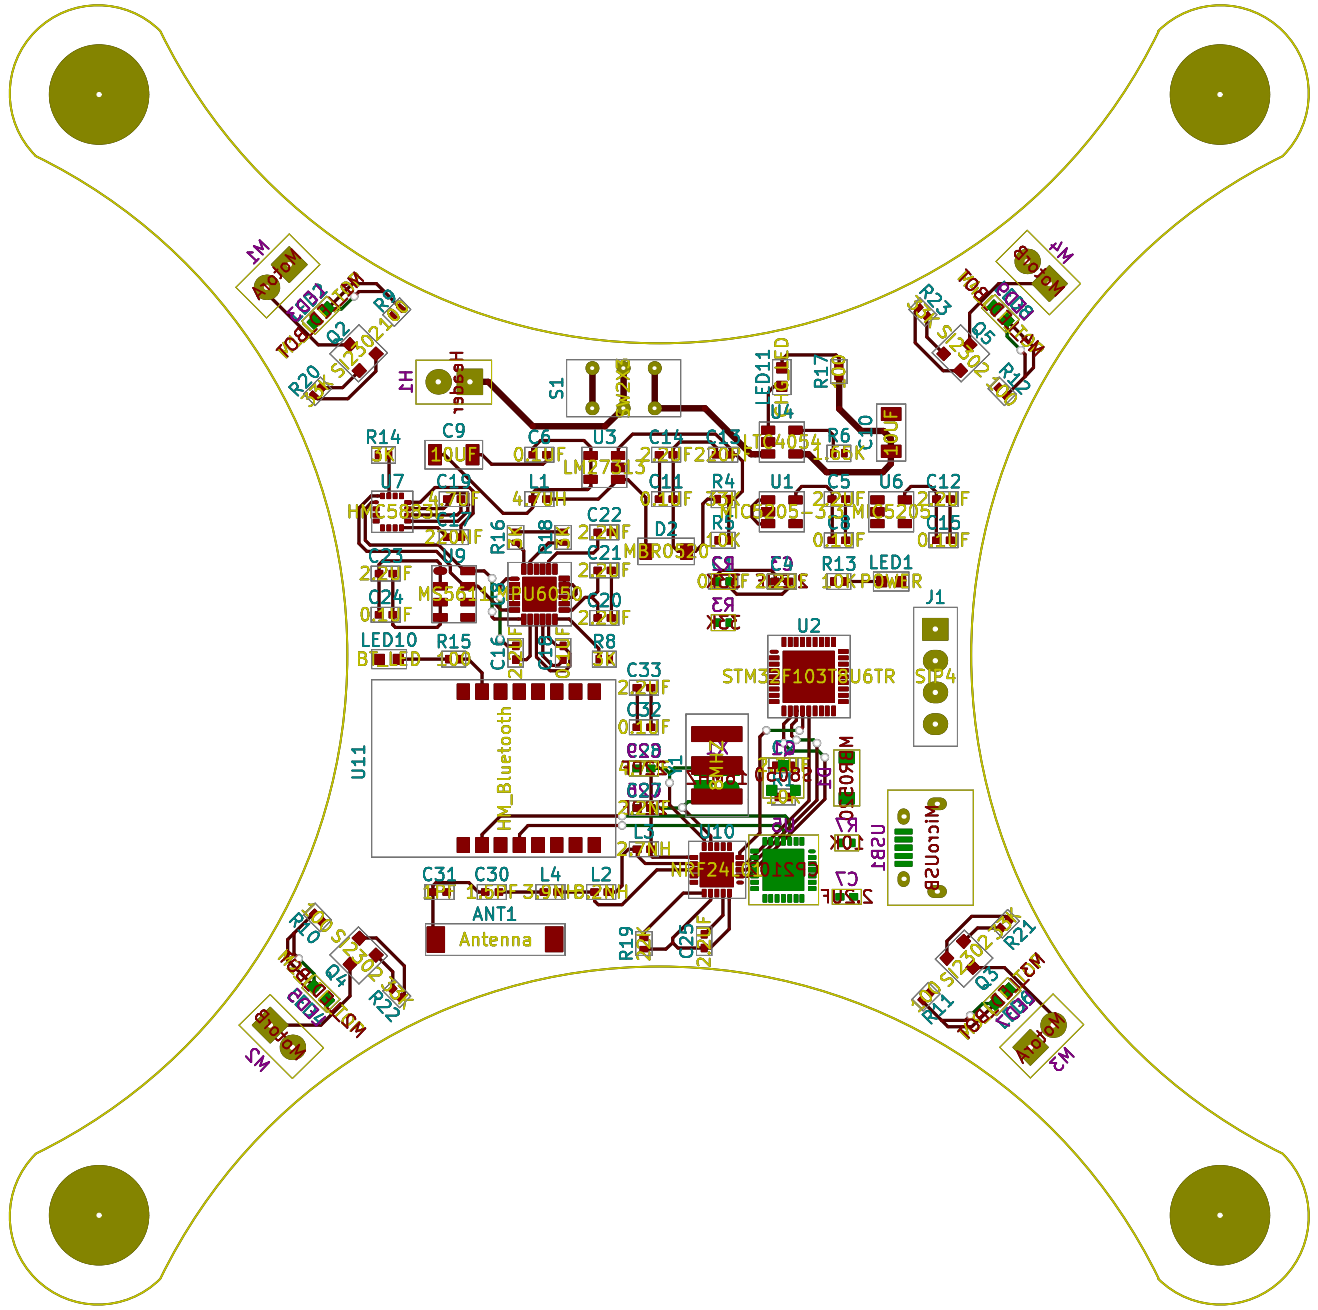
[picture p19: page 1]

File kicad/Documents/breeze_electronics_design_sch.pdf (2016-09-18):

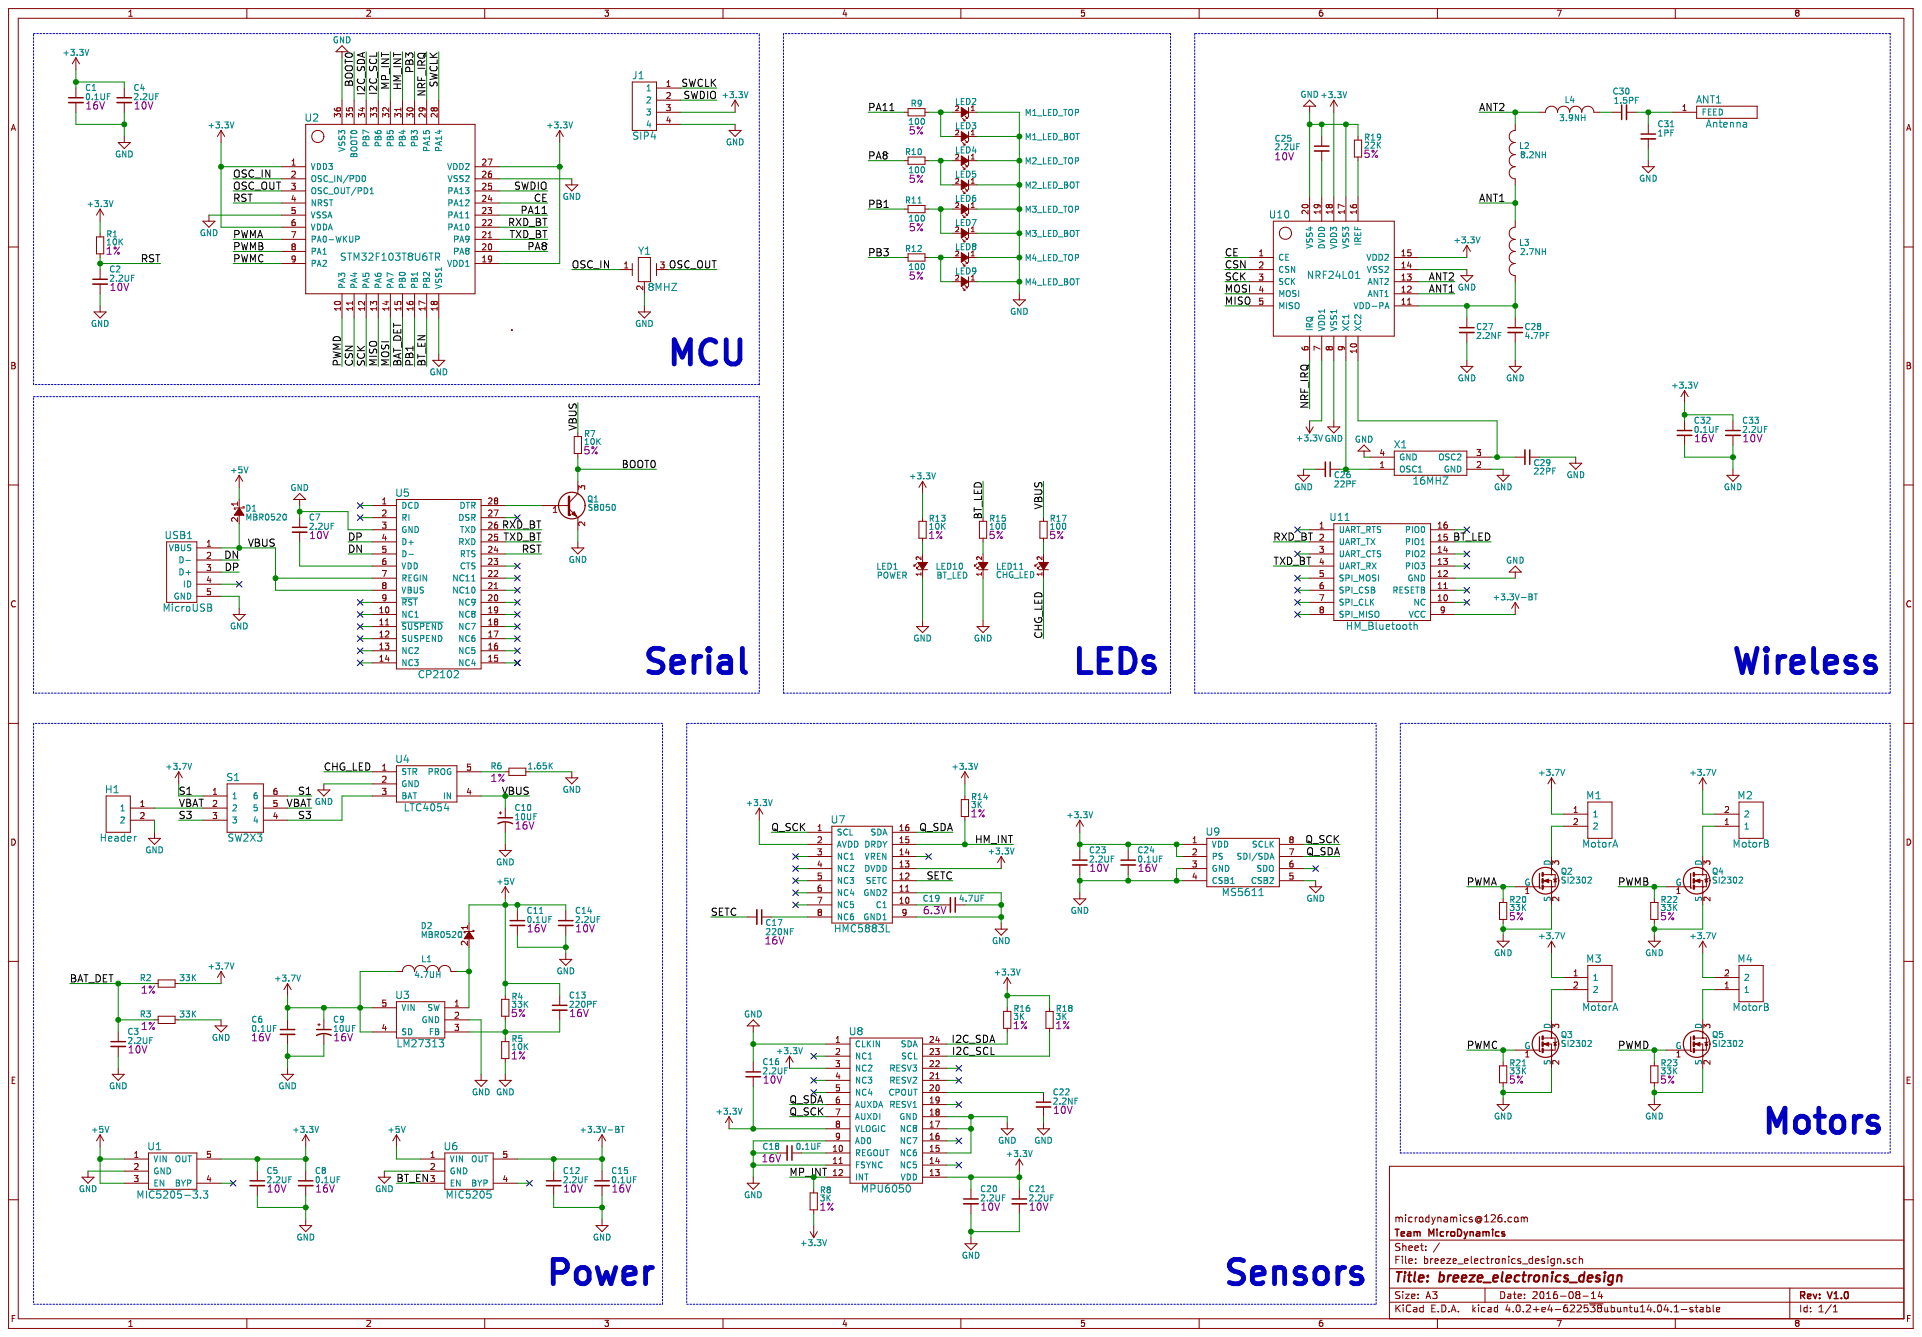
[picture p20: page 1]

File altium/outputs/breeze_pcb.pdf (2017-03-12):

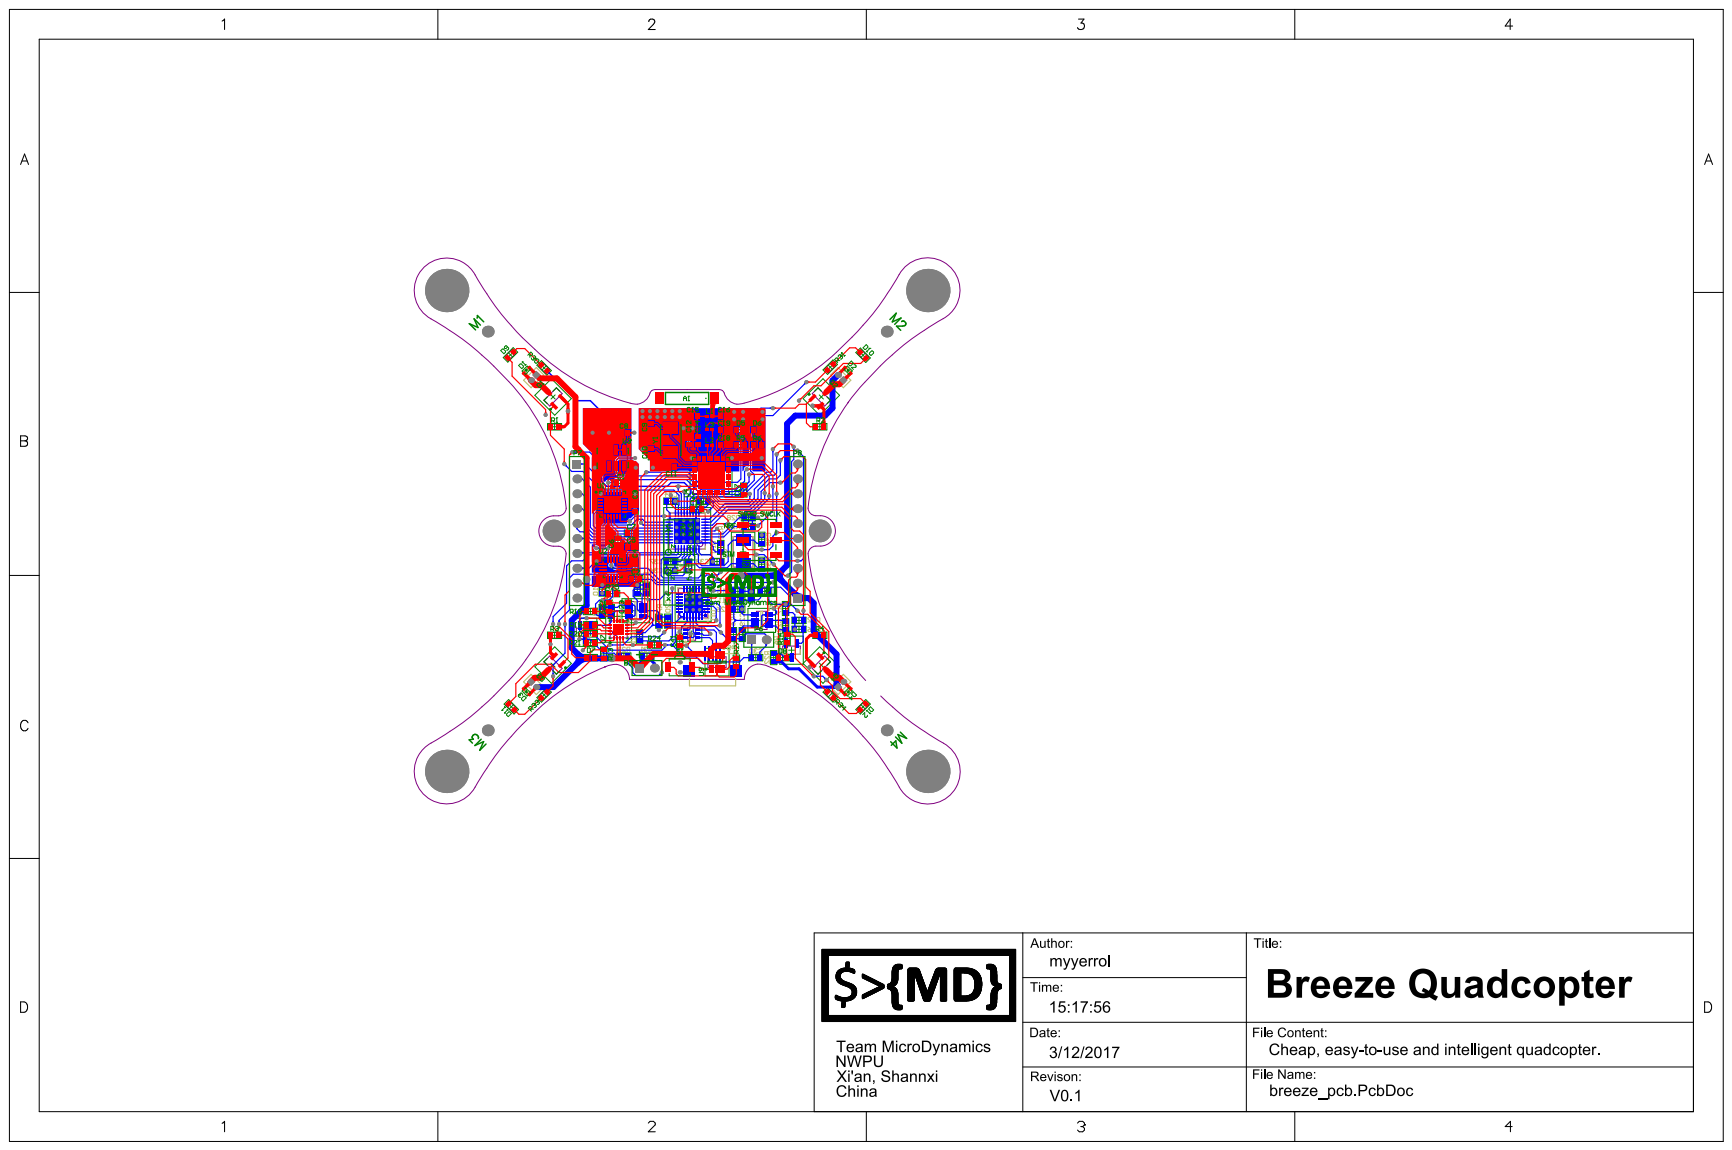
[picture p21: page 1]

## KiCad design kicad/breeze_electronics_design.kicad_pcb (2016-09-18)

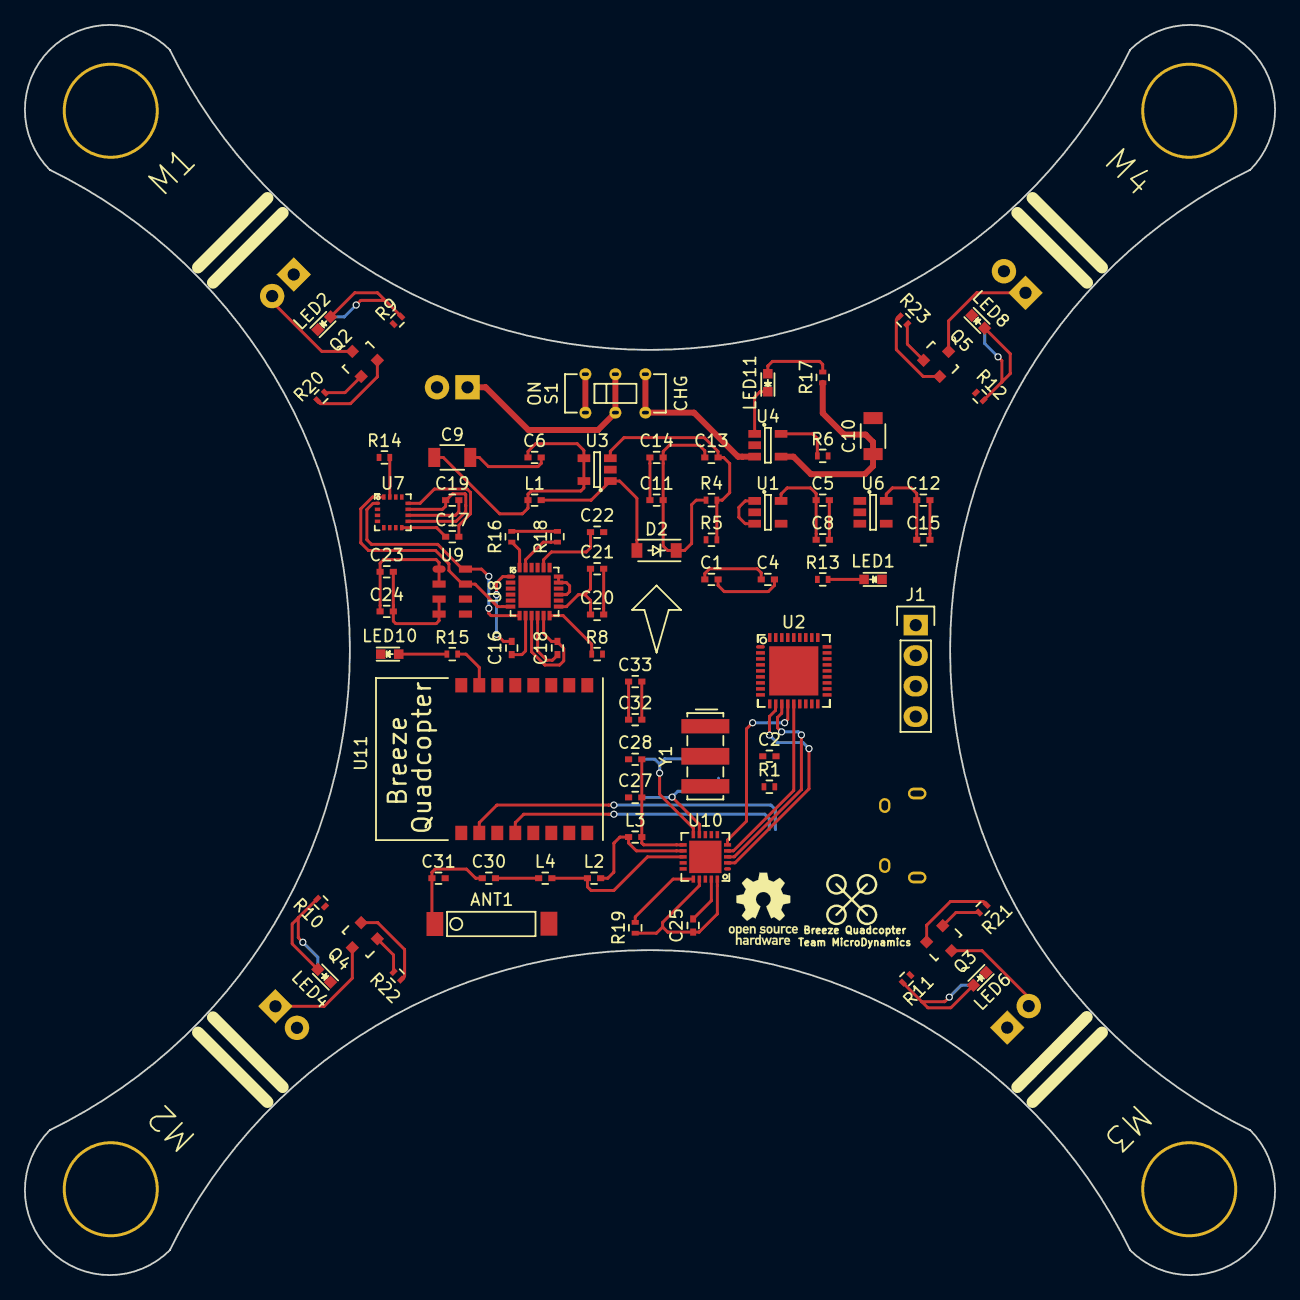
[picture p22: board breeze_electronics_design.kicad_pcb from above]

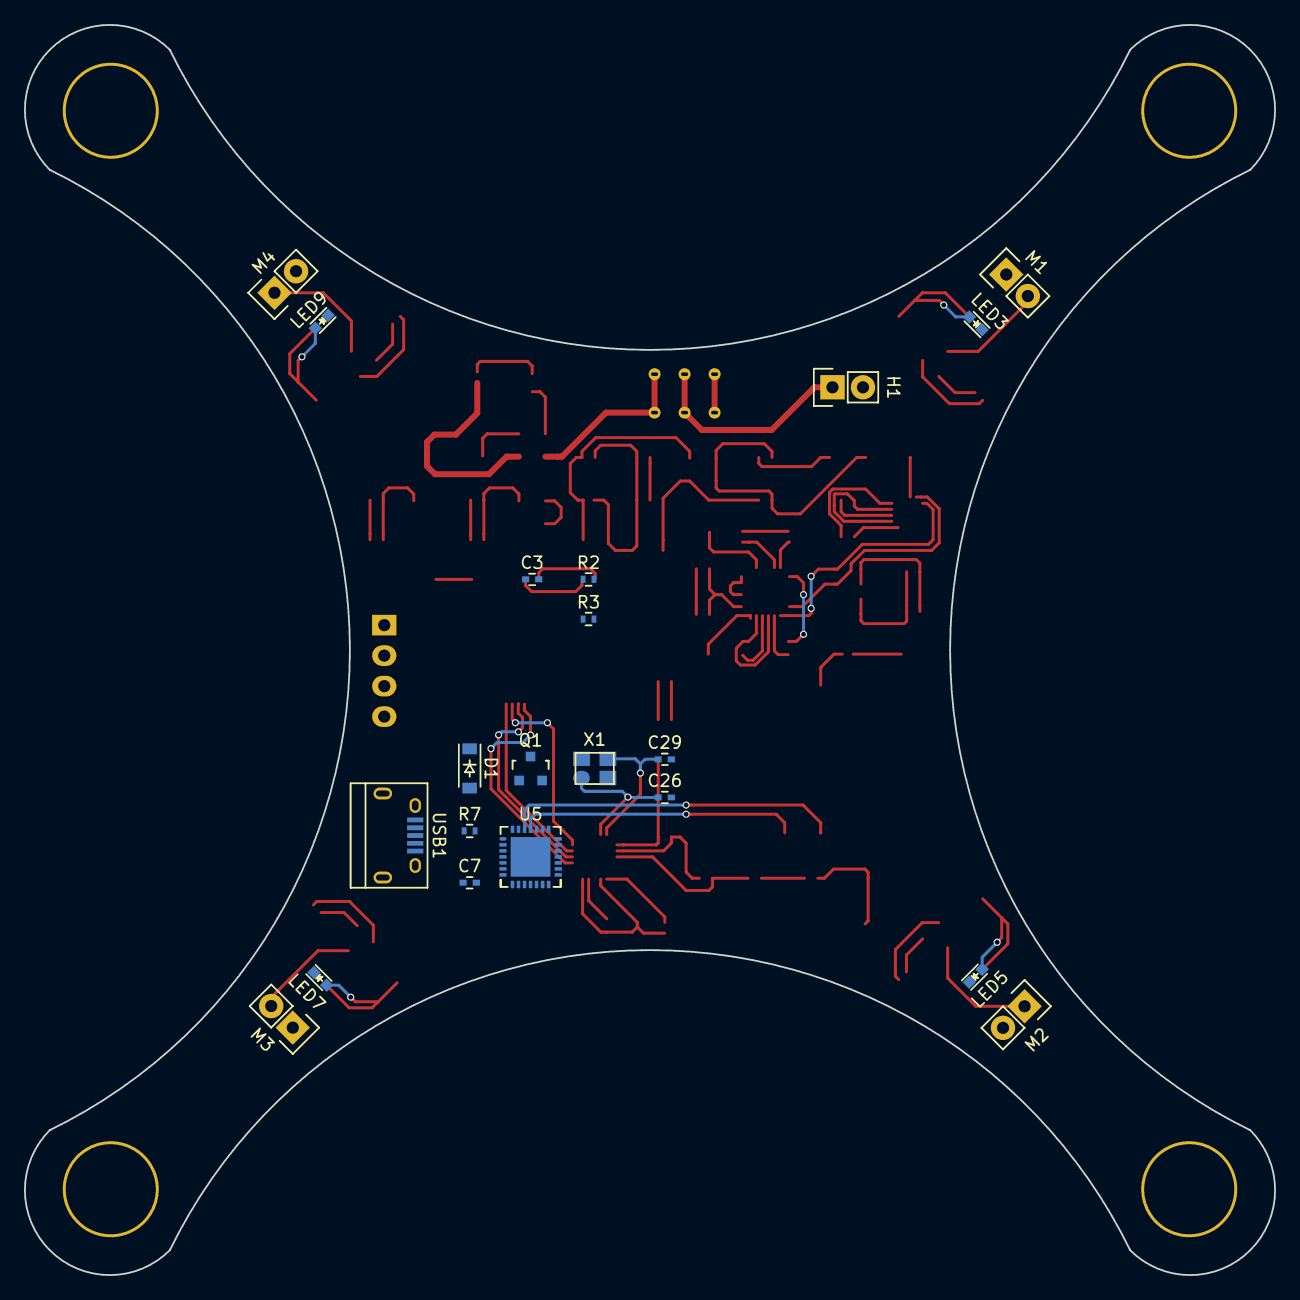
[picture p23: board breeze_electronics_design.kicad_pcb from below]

Board: 2 copper layers, 104.1 x 104.1 mm, 100 parts (21 on the bottom side), 100 nets.

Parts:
ANT1: Antenna; SMD_AN9520
C1, C6, C8, C11, C15, C18, C24, C32: 0.1UF; C_0402
C2, C3, C4, C5, C7, C12, C14, C16, C20, C21, C23, C25, C33: 2.2UF; C_0402
C9, C10: 10UF; C_1206
C13: 220PF; C_0402
C17: 220NF; C_0402
C19: 4.7UF; C_0402
C22, C27: 2.2NF; C_0402
C26, C29: 22PF; C_0402
C28: 4.7PF; C_0402
C30: 1.5PF; C_0402
C31: 1PF; C_0402
D1, D2: MBR0520; SOD-123
H1: Header; Pin_Header_Straight_1x02
J1: SIP4; Pin_Header_Straight_1x04
L1: 4.7UH; SMD_L0402
L2: 8.2NH; SMD_L0402
L3: 2.7NH; SMD_L0402
L4: 3.9NH; SMD_L0402
LED1: POWER; LED_0603
LED2: M1_LED_TOP; LED_0603
LED3: M1_LED_BOT; LED_0603
LED4: M2_LED_TOP; LED_0603
LED5: M2_LED_BOT; LED_0603
LED6: M3_LED_TOP; LED_0603
LED7: M3_LED_BOT; LED_0603
LED8: M4_LED_TOP; LED_0603
LED9: M4_LED_BOT; LED_0603
LED10: BT_LED; LED_0603
LED11: CHG_LED; LED_0603
M1, M3: MotorA; Pin_Header_Straight_1x02
M2, M4: MotorB; Pin_Header_Straight_1x02
Q1: S8050; SOT-23
Q2, Q3, Q4, Q5: SI2302; SOT-23
R1, R5, R7, R13: 10K; R_0402
R2, R3, R4, R20, R21, R22, R23: 33K; R_0402
R6: 1.65K; R_0402
R8, R14, R16, R18: 3K; R_0402
R9, R10, R11, R12, R15, R17: 100; R_0402
R19: 22K; R_0402
S1: SW2X3; DIP_SW2x3
U1: MIC5205-3.3; SOT-23-5
U2: STM32F103T8U6TR; VFQFPN_STM32F103T8U6TR
U3: LM27313; SOT-23-5
U4: LTC4054; SOT-23-5
U5: CP2102; QFN_CP2102
U6: MIC5205; SOT-23-5
U7: HMC5883L; LPCC_HMC5883L
U8: MPU6050; QFN_MPU6050
U9: MS5611; QFN_MS5611
U10: NRF24L01; QFN_NRF24L01
U11: HM_Bluetooth; SMD_HM
USB1: MicroUSB; USB_Micro-B
X1: 16MHZ; SMD_XTAL3225
Y1: 8MHZ; Resonator_7.2x3mm

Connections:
/ANT1: L2.1, L3.2, U10.12
/ANT2: L2.2, L4.1, U10.13
/BAT_DET: C3.1, R2.1, R3.1, U2.15
/BOOT0: Q1.3, R7.2, U2.35
/BT_EN: U2.17, U6.3
/BT_LED: R15.1, U11.15
/CE: U2.24, U10.1
/CHG_LED: LED11.1, U4.1
/CSN: U2.11, U10.2
/DN: U5.5, USB1.2
/DP: U5.4, USB1.3
/HM_INT: R14.2, U2.31, U7.15
/I2C_SCL: R18.2, U2.33, U8.23
/I2C_SDA: R16.2, U2.34, U8.24
/MISO: U2.13, U10.5
/MOSI: U2.14, U10.4
/MP_INT: R8.1, U2.32, U8.12
/NRF_IRQ: U2.29, U10.6
/OSC_IN: U2.2, Y1.1
/OSC_OUT: U2.3, Y1.3
/PA8: R10.1, U2.20
/PA11: R9.1, U2.23
/PB1: R11.1, U2.16
/PB3: R12.1, U2.30
/PWMA: Q2.1, R20.1, U2.7
/PWMB: Q4.1, R22.1, U2.8
/PWMC: Q3.1, R21.1, U2.9
/PWMD: Q5.1, R23.1, U2.10
/Q_SCK: U7.1, U8.7, U9.8
/Q_SDA: U7.16, U8.6, U9.7
/RST: C2.1, R1.2, U2.4, U5.24
/RXD_BT: U2.22, U5.26, U11.2
/S1: S1.1, S1.6
/S3: S1.3, S1.4, U4.3
/SCK: U2.12, U10.3
/SETC: C17.2, U7.12
/SWCLK: J1.1, U2.28
/SWDIO: J1.2, U2.25
/TXD_BT: U2.21, U5.25, U11.4
/VBAT: H1.1, S1.2, S1.5
/VBUS: C10.1, D1.2, R7.1, R17.1, U4.4, U5.7, U5.8, USB1.1
unnamed: ANT1.1, C30.2, C31.1
unnamed: C1.1, C4.1
unnamed: C1.2, C4.2
unnamed: C5.1, C8.1, U1.5
unnamed: C5.2, C8.2
unnamed: C6.1, C9.1, L1.1, U3.4, U3.5
unnamed: C6.2, C9.2
unnamed: C7.1, U5.3
unnamed: C7.2, U5.6
unnamed: C11.1, C13.1, C14.1, D2.1, R4.1
unnamed: C11.2, C14.2
unnamed: C12.1, C15.1, U6.5
unnamed: C12.2, C15.2
unnamed: C13.2, R4.2, R5.1, U3.3
unnamed: C16.1, U8.1
unnamed: C16.2, U8.8
unnamed: C17.1, U7.8
unnamed: C18.1, U8.10
unnamed: C18.2, U8.9, U8.11
unnamed: C19.1, U7.9, U7.11
unnamed: C19.2, U7.10
unnamed: C20.1, C21.1, U8.13
unnamed: C20.2, C21.2
unnamed: C22.1, U8.20
unnamed: C23.1, C24.1, U9.1, U9.2
unnamed: C23.2, C24.2, U9.3, U9.4
unnamed: C25.1, R19.1, U10.17, U10.20
unnamed: C25.2, U10.19
unnamed: C26.1, U10.9, X1.1
unnamed: C27.1, C28.1, L3.1, U10.11
unnamed: C29.2, U10.10, X1.3
unnamed: C30.1, L4.2
unnamed: C32.1, C33.1
unnamed: C32.2, C33.2
unnamed: D2.2, L1.2, U3.1
unnamed: LED1.2, R13.2
unnamed: LED2.1, LED3.1, LED4.1, LED5.1, LED6.1, LED7.1, LED8.1, LED9.1
unnamed: LED2.2, LED3.2, R9.2
unnamed: LED4.2, LED5.2, R10.2
unnamed: LED6.2, LED7.2, R11.2
unnamed: LED8.2, LED9.2, R12.2
unnamed: LED10.2, R15.2
unnamed: LED11.2, R17.2
unnamed: M1.2, Q2.3
unnamed: M2.1, Q4.3
unnamed: M3.2, Q3.3
unnamed: M4.1, Q5.3
unnamed: Q1.1, U5.28
unnamed: Q2.2, R20.2
unnamed: Q3.2, R21.2
unnamed: Q4.2, R22.2
unnamed: Q5.2, R23.2
unnamed: R6.1, U4.5
unnamed: R16.1, R18.1
unnamed: R19.2, U10.16
unnamed: U1.1, U1.3
unnamed: U2.1, U2.6
unnamed: U2.19, U2.27
unnamed: U8.15, U8.17, U8.18

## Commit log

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2016-08-15 Finish the component library
    [breeze_electronics_design.sch]
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2016-08-16 Finish the basic schematic
    [breeze_electronics_design.sch]
2016-08-17 Modify the schematic of controller
    [breeze_electronics_design.sch]
2016-08-17 Modify the schematic of leds
    [breeze_electronics_design.sch]
2016-08-17 Modify the schematic of usb_to_serial
    [breeze_electronics_design.sch]
2016-08-17 Modify the schematic of wireless
    [breeze_electronics_design.sch]
2016-08-18 Modify the schematic of motor
    [breeze_electronics_design.sch]
2016-08-18 Modify the schematic of sensor
    [breeze_electronics_design.sch]
2016-08-18 Modify the schematic of power
    [breeze_electronics_design.sch]
2016-08-18 Fix some ERC's errors
    [breeze_electronics_design.sch]
2016-08-18 Add voltage and accuracy fields
    [breeze_electronics_design.sch]
2016-08-18 Modify the format of components
    [breeze_electronics_design.sch]
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2016-08-20 Fix HMC5883L's name
    [breeze_electronics_design.sch]
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2016-08-22 Modify the power's name
    [breeze_electronics_design.sch]
2016-08-22 Modify the schematic of MCU
    [breeze_electronics_design.sch]
2016-08-23 Modify the schematic of Serial
    [breeze_electronics_design.sch]
2016-08-23 Modify the schematic of Sensors
    [breeze_electronics_design.sch]
2016-08-23 Modify the schematic of Motors
    [breeze_electronics_design.sch]
2016-08-23 Fix schematic's name bug
    [breeze_electronics_design.sch]
2016-08-23 Update the schematic's image and pdf
    [breeze_electronics_design.sch]
2016-08-24 Fix pin's number bug
2016-08-24 Modify the power and components' position
    [breeze_electronics_design.sch]
2016-08-25 Add the shape of breeze in PCB
    [breeze_electronics_design.kicad_pcb, breeze_electronics_design.sch]
2016-08-25 Modify the clearance of footprint's name
2016-08-25 Add the motor's base
    [breeze_electronics_design.kicad_pcb]
2016-08-26 Finish the layout of LEDs and Motors
    [breeze_electronics_design.kicad_pcb]
2016-08-26 Finish the layout of Wireless
    [breeze_electronics_design.kicad_pcb]
2016-08-26 Finish the layout of Sensors
    [breeze_electronics_design.kicad_pcb]
2016-08-26 Finish the layout of Power
    [breeze_electronics_design.kicad_pcb]
2016-08-26 Modify the line's length of GND
    [breeze_electronics_design.sch]
2016-08-27 Finish the layout of PCB
    [breeze_electronics_design.kicad_pcb, breeze_electronics_design.sch]
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2016-08-27 Fix some bugs
    [breeze_electronics_design.sch]
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2016-08-28 Finish the basic check of layout
    [breeze_electronics_design.kicad_pcb]
2016-08-29 Finish the basic wiring of LEDs
    [breeze_electronics_design.kicad_pcb]
2016-08-29 Modify the GND from pin to component
    [breeze_electronics_design.sch]
2016-08-30 Relocate the footprints of Wireless
    [breeze_electronics_design.kicad_pcb, breeze_electronics_design.sch]
2016-08-30 Modify the redundant line
    [breeze_electronics_design.sch]
2016-08-30 Modify the footprints of Sensors
    [breeze_electronics_design.kicad_pcb]
2016-08-30 Relocate the footprints of Power
    [breeze_electronics_design.kicad_pcb]
2016-08-31 Relocate the footprints of MCU and Serial
    [breeze_electronics_design.kicad_pcb]
2016-08-31 Make the module of Serial to the pcb's back
    [breeze_electronics_design.kicad_pcb]
2016-09-12 Modify the clearance from 0.2 to 0.15
    [breeze_electronics_design.kicad_pcb]
2016-09-13 Adjust the layout of Sensor module
    [breeze_electronics_design.kicad_pcb]
2016-09-13 Finish the major layout
    [breeze_electronics_design.kicad_pcb]
2016-09-13 Move the PCB to the center of drawing
    [breeze_electronics_design.kicad_pcb]
2016-09-13 Finish the automatic routing of Motors
    [breeze_electronics_design.kicad_pcb]
2016-09-16 Finish the wiring of Motors
    [breeze_electronics_design.kicad_pcb]
2016-09-17 Modify the wiring's layout of Motors
    [breeze_electronics_design.kicad_pcb]
2016-09-17 Modify the layout of footprints accurately
    [breeze_electronics_design.kicad_pcb]
2016-09-18 Finish the layout of all footprints
    [breeze_electronics_design.kicad_pcb]
2016-09-18 Fix pin's dislocation of NRF24L01
    [breeze_electronics_design.sch]
2016-09-18 Finish the wiring of Wireless
    [breeze_electronics_design.kicad_pcb]
2016-09-18 Finish the major wiring of Sensors
    [breeze_electronics_design.kicad_pcb]
2016-09-18 Finish the major wiring of Power
    [breeze_electronics_design.kicad_pcb]
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2017-01-14 Format the kicad's project of breeze_std
    [breeze_electronics_design.kicad_pcb, breeze_electronics_design.sch]
2017-01-17 Readjust the organization of project
    [breeze_electronics_design.kicad_pcb, breeze_electronics_design.sch]
2017-01-23 Add motor circuit in cadence design
    [BREEZE_ELECTRONICS_DESIGN.DSN]
2017-01-23 Add schematic library and NRF24L01 part
    [BREEZE_ELECTRONICS_DESIGN.DSN]
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2017-01-24 Add AN9520-245 part and modify circuit
    [BREEZE_ELECTRONICS_DESIGN.DSN]
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2017-01-28 Stop circuit design temporarily
    [BREEZE_ELECTRONICS_DESIGN.DSN]
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2017-02-22 Add the component of MPU6050
    [breeze_design_library.SchLib]
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2017-02-25 Fix the bug
    [breeze_motor.SchDoc, breeze_power.SchDoc]
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2017-02-25 Fix the directional bug for motors
    [breeze_motor.SchDoc]
2017-02-25 Fix the pin's bug of HMC5883L
    [breeze_design_library.SchLib, breeze_motor.SchDoc]
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2017-02-27 Modify the bugs
    [breeze_motor.SchDoc, breeze_sensor.SchDoc]
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2017-02-28 Fix the warning of Net Labels
    [breeze_controller.SchDoc, breeze_motor.SchDoc, breeze_power.SchDoc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]
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2017-03-04 Add the MSS-22D18G2 and fix some bugs
    [breeze_design_library.PcbLib, breeze_design_library.SchLib]
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2017-03-06 Fix the collision of components at the bottom layer
    [breeze_pcb.PcbDoc]
2017-03-06 Fix the collision of components at the top layer
    [breeze_pcb.PcbDoc]
2017-03-06 Fix all the collisions
    [breeze_pcb.PcbDoc]
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2017-03-07 Fix the bug of clearance constraints
    [breeze_design_library.PcbLib, breeze_pcb.PcbDoc]
2017-03-07 Finish the basic route on the top layer
    [breeze_pcb.PcbDoc]
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2017-03-07 Finish the basic routes on the bottom layer
    [breeze_pcb.PcbDoc]
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2017-03-08 Finish the bus's route on the top layer
    [breeze_pcb.PcbDoc]
2017-03-08 Swap the positions of two net labels
    [breeze_controller.SchDoc]
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2017-03-12 Finish the copper of DGND on top layer
    [breeze_pcb.PcbDoc]
2017-03-12 Finish the copper of DGND on bottom layer
    [breeze_pcb.PcbDoc]
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2017-03-12 Fix some violations
    [breeze_pcb.PcbDoc]
2017-03-12 Fix an un-routed bug
    [breeze_pcb.PcbDoc]
2017-03-12 Fix double un-routed bugs
    [breeze_pcb.PcbDoc]
2017-03-12 Fix the bug of isolated copper
    [breeze_pcb.PcbDoc]
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

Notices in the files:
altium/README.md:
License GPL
